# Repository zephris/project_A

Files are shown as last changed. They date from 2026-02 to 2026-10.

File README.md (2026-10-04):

# Project PHBox 
An attempt at an ultra-slim hitbox supporting 13/16 buttom layout, per-key lighting and minimum wired latency, all with uncompromising thinness and weight.

## Specifications
- Dimensions: 296*196*16.5mm (Clap shell customisables)
- Processor: RP2350A
- Connetivity: Wired
- Controller modes: X-input mode, Switch mode, PS3 / D-input mode, Keyboard mode
- Switch: Kailh Choc V1 (hotswappable), with compatability for soldered V2s and 5-pin profiles (Will require custom top-plate with 5-pin full-size switches).
- System compatability: Windows/Unix, Switch/Switch 2, PS3, IpadOS, iOS (USB-C based)
- Feature: 
    - OLED screen
    - Programmable key-mapping with GP-2040-CE firmware
    - Per-key RGB lighting and case-lined diffused lighting
    - Foam-lined, gasket-mounted top-plate to reduce force transfer back onto finger
    - USB-C 3.1 connectivity
    - Stealth flush-sitting passthrough port
    - overclocked for sub-1ms input delay
    - CNC'd alluminium lining plate for thermal dissipation

## TODO:

## Current KiCad project

Latest copper/via cleanup and focused JLCPCB checks: [review and recovery record](stage2_work/fill_via_cleanup_2026-10-03/README.md).

Use the root `Flatbox-rev8.kicad_pro`. The accepted PCB has four copper layers with two dedicated inner GND planes. The 2026-10-03 main-project merge passes ERC, DRC and schematic parity with zero findings and zero open connections. Validation evidence, recovery backup and remaining release checks are in [the merge record](stage2_work/main_merge_2026-10-03/README.md). Eight unnecessary routing bridges were subsequently simplified, removing 16 vias; [the bridge record](stage2_work/bridge_simplification_2026-10-03/README.md) contains the latest verification and PCB backup.

Latest power/USB routing repair and exact validation: [2026-10-04 review](stage2_work/direct_power_usb_2026-10-03/README.md).

## Testing this checkpoint on another computer

Use **KiCad 10**, including its standard symbol/footprint libraries. Open the root `Flatbox-rev8.kicad_pro`; do not open an old autosave, backup or fabrication output. Required project-local libraries and the switch 3D model are included. Some inherited optional third-party 3D model references may be unresolved unless their libraries are installed; this is not proof of mechanical clearance.

Latest accepted changes: [LX cutout, USB ESD/routing and C42](stage2_work/lx_usb_c42_2026-10-04/README.md). This checkpoint contains 146 footprints and 440 numbered pad entries. Recorded exact-main ERC, DRC, unconnected and schematic-parity findings are all zero. Rerun these checks after opening the checkout:

```sh
kicad-cli sch erc --format json -o phbox-erc.json Flatbox-rev8.kicad_sch
kicad-cli pcb drc --refill-zones --schematic-parity --format json -o phbox-drc.json Flatbox-rev8.kicad_pcb
kicad-cli sch export netlist --format kicadxml -o phbox-netlist.xml Flatbox-rev8.kicad_sch
```

On macOS, use `/Applications/KiCad/KiCad.app/Contents/MacOS/kicad-cli` if it is not on PATH. On Windows, use the executable in the KiCad installation's `bin` directory. Review the reports, not just the command exit status. The committed reports record the originating computer and revision; they do not substitute for a fresh run elsewhere.

**Not a manufacturing or firmware release:** historical `order/`, `production/`, BOM and placement exports are stale. No PHBox-validated UF2 or completed SPICE testbench is included. USB2 is intended for a low-power authenticator dongle, not a general-purpose controller power outlet. Firmware mapping, 50% RGB brightness, authentication, suspend current, upstream power budget, USB/ESD, thermal and enclosure tests remain required. Large local candidates/recovery snapshots are deliberately excluded from Git; AGENTS.md retains their provenance for the original workstation.

## Testing methodology and future release steps

This is a validation roadmap, **not a record of completed hardware tests**. The completed checks are schematic/PCB consistency, ERC, DRC, zone refill and pad-net reconciliation. Simulation, firmware behaviour, physical measurements and manufacturing qualification remain future work.

### Configuration baseline

Record the Git commit, KiCad version, board revision, exact firmware SHA-256, exported firmware settings, host OS/console, dongle model, cable and instruments for every test run. Do not infer firmware settings from the schematic.

| Function | Intended configuration |
|---|---|
| MCU/upstream USB | Embedded RP2350A; USB1 is a USB-C **full-speed USB device**, not a USB 3.1 data link |
| OLED | Winstar WEA012864DWPP3N00003, 128×64 I²C; +3V3 supply; GPIO12 SDA / GPIO13 SCL |
| RGB | GPIO8; GRB; D1–D16 at SW1–SW16, then D17–D20 edge LEDs left-to-right; 20 total |
| Brightness | Provisional maximum 127/255 (~50%), including edge effects; verify on the actual firmware |
| 13-button mode | Disable SW6, SW7, SW16 and LED indices 5, 6, 15; same fully populated PCB as 16-button mode |
| USB2 host data | GPIO20 D+ / GPIO21 D− |
| USB2 power control | GPIO7 EN; GPIO17 active-low FAULT input; default off at reset |

USB2 is current-limited by U7/TPS2553 with 200 kΩ ILIM and two 100 µF output capacitors. Its provisional limit is about 115–159 mA, not a promise that any particular dongle works. Explicitly implement and test startup/fault handling; selecting a GP2040-CE enable pin alone does not establish it.

### 1. Software and design regression checks

- Run the KiCad commands above on the exact checkout being tested; retain JSON reports and a fresh XML netlist. Resolve every new finding or document its physical justification; do not weaken rules to obtain a pass.
- Compare symbol pins, PCB pads and actual copper for MCU power/USB, OLED SDA/SCL, LED DIN/DOUT, U6 orientation, U7 switched output and U8 ESD pinout. ERC/DRC alone cannot identify a mutually consistent but incorrect library pin map.
- Confirm zone fills and the local LX exclusion on In1.Cu/In2.Cu/B.Cu. Preserve the neighboring PGND return and connected inner ground planes.
- Keep all test artifacts under a run-specific directory, with pass/fail criteria, model assumptions, raw data and any unresolved limitations. A prior report does not validate a changed board.

### 2. Automated SPICE tests — planned, not implemented

Use separate simulation schematics/netlists so that test sources and behavioural loads cannot accidentally enter the manufacturing schematic. KiCad uses ngspice; batch runs can be driven by a Python/pytest harness and SPICE `.meas` results. Begin with [TI's unencrypted TPS2553 transient model](https://www.ti.com/product/TPS2553#design-development), verify model-pin mapping and ngspice compatibility, and reproduce its reference test before applying it to PHBox.

| Testbench | Sweeps and measurements |
|---|---|
| USB2 startup | Supply ramp, EN timing, 160/200/240 µF output bank, unloaded and representative dongle loads; output rise time, current and FAULT duration |
| USB2 overload/recovery | Loads below/above the limit; output voltage, limiting and recovery after fault removal |
| Shared +5V supply | Cable/source resistance, RGB pulsed-current loads and host hot-plugging; supply minima and settling |
| 3.3V/OLED supply | Startup and load steps using an appropriate regulator model; rail limits and transient response |
| Bypass/data networks | Effective capacitance, ESR, estimated trace/via R/L/C and suitable driver/input models; impedance, ringing and settling |

Use datasheet bounds and measured loads when available; distinguish typical, worst-case and assumed values. Include MLCC bias effects and component tolerances rather than relying on ideal nominal capacitors. A Monte Carlo sample is not a guaranteed worst-case bound. Setting `.temp` does not simulate enclosure heating or self-heating. PCB parasitics are not automatically extracted accurately merely by opening the board in KiCad.

Define assertions from the actual receiving-device voltage/timing limits and the selected models. Do not claim RP2350 firmware execution, regulator-loop stability, USB compliance or ESD survival from generic behavioural models. The present repository has **no complete SPICE test suite**. See [KiCad's simulator documentation](https://docs.kicad.org/10.0/en/eeschema/eeschema.html#simulator).

### 3. Prototype bring-up and power measurements

1. Inspect assembly, polarity and solder joints; check resistance between each rail and GND before power. Support the OLED mechanically; its electrical leads are not mounting posts.
2. Use a current-limited supply through the intended upstream power path, with RGB and USB2 initially off. Never tie a bench supply to a computer's VBUS without a suitable isolated injection arrangement.
3. Verify +5V, +3V3 and the configured MCU core supply; check startup/ripple with short oscilloscope probe returns. Then enable OLED, RGB and USB2 separately and record their incremental loads.
4. Capture upstream current and rail voltages during enumeration, OLED illumination, all-white RGB at 127/255, animation transitions, dongle hot-plugging and repeated boot cycles. A slow USB meter cannot establish peak current or inrush compliance.
5. Use a controlled electronic load for USB2 overload/recovery testing. Capture U7 IN/OUT, EN and FAULT; distinguish legitimate reservoir charging from a sustained fault. Verify the dongle also starts successfully at the low current-limit corner.
6. Test actual USB suspend/resume, not just user inactivity or black LEDs. The existing ~10 mA typical LED-idle estimate is already above the 2.5 mA USB suspend target; power gating or a verified low-power solution may require a hardware revision.

The provisional 500 mA average-current budget is **not closed by measurement**. RGB PWM peaks, upstream USB power declaration/configuration, cable drop, startup and fuse derating remain checks. Stop on abnormal current, temperature or rail collapse; do not use an uncontrolled wire short as a fault test.

### 4. Firmware and interoperability tests

- Verify each action/option button, simultaneous presses, SOCD behaviour and both 13/16-button modes. Confirm disabled buttons/LEDs stay disabled after reboot.
- Exercise each LED individually and solid red/green/blue to verify index/colour order; verify OLED refresh and button activity together.
- Test enumeration, repeated reconnects and suspend/resume on the intended operating systems, both USB-C cable orientations and representative compliant cables.
- Use a Python/pytest harness with HIDAPI in a supported HID mode for automated report checks. End-to-end input testing needs real button stimulation; software-generated input on the PC does not test the PCB contacts. Do not assume HID tooling tests XInput modes identically.
- Use Wireshark/USBPcap on Windows or usbmon on Linux for PC-side protocol diagnostics. The PC cannot directly capture the USB2 dongle bus behind the MCU; use firmware logs or an inline USB protocol analyzer for that side.
- Test the actual authenticator and target console over extended sessions, including unplug/replug and recovery. Successful PC enumeration is not proof of console authentication or official platform approval.
- Measure physical-input-to-host-report latency with an external stimulus/time reference; USB polling interval alone does not establish end-to-end latency.

Tools: [HIDAPI](https://github.com/libusb/hidapi), [pytest](https://docs.pytest.org/en/stable/), [Wireshark USB capture](https://wiki.wireshark.org/CaptureSetup/USB), [USB-IF protocol/electrical tools](https://www.usb.org/compliancetools). USB3CV can test USB 2.0 devices, but use a dedicated test computer/controller because it takes over the host controller.

### 5. Physical qualification

- Check regulator startup/ripple and core-rail load transients. The LX keepout is a layout improvement, not proof of regulator stability or reduced emissions.
- Test the assembled enclosure at room temperature and the specified **60 °C maximum ambient** until temperatures stabilize. Record fuse, regulator, U7 and MCU temperatures/rail behaviour. Surface temperature is not junction temperature; do not credit the aluminium plate as cooling without verified thermal coupling.
- Obtain factory stackup/impedance data or a coupon; obtain appropriate full-speed USB waveform/eye measurements using a suitable scope, probe and fixture. Packet captures and matched via counts do not establish 90 Ω or electrical compliance.
- Use a competent lab for controlled ESD and applicable emissions/immunity testing of the assembled enclosure and connectors. Do not substitute improvised static shocks for the specified test method.
- Verify actual switch housing/keycap light paths, solder access, OLED standoffs/window, USB insertion clearance, insulating layers, screw/hole clearances and the total enclosure stack. Component bodies/courtyards retain 2.5 mm PCB-edge clearance except USB1 and the four edge LEDs; unresolved mounting-hole exceptions must be explicitly approved.

### 6. Manufacturing and release gate

1. Freeze one reviewed source revision. Manufacture one fully populated 16-button board; 13-button operation is a firmware/mechanical-cover mode, not a reduced BOM.
2. Recheck exact MPN, package, footprint/pinout, polarity, lifecycle and current supplier availability. For JLCPCB, verify each LCSC identity and Basic/Extended status at ordering time. Confirm the SK6805-EC15 purchased variant against the `-001` datasheet; generic substitutes are not automatically acceptable.
3. Agree the four-layer stackup, copper weights, impedance geometry, drill/via limits, soldermask, stencil/reflow process, double-sided assembly and mechanical tolerances with the manufacturer. Review exposed-pad soldering, via treatment, 0402 access, USB2 on B.Cu and opposite-side U8/C44 placement.
4. Regenerate BOM, top/bottom placement files, all four copper-layer Gerbers, masks, silkscreens, Edge.Cuts and plated/non-plated drills **from that same revision**. Inspect them in an independent viewer; verify orientation, mirror conventions, drill alignment and placement datum. Never reuse the historical `order/` or `production/` exports.
5. Review the assembler's BOM/CPL matching and visual assembly preview. Check every polarized IC/diode/capacitor, connector and LED rotation; retain explicit DNP/exclusion and hand-assembly notes. Include OLED mounting hardware and other non-schematic mechanical items separately.
6. Build a small first-article batch and execute the above tests before a larger production run. Clearly distinguish a risk-accepted engineering prototype order from a qualified production release.
7. Archive source commit, tool versions, reports/raw captures, approved parts/alternatives, exact fabrication files, assembly preview, mechanical drawings, firmware image/hash and exported settings for both modes. Attach a release manifest/checksums so the build can be reproduced.

Manufacturing exit requires reviewed electrical/physical checks, proven power/suspend/thermal behaviour, verified mechanical fit, compatible firmware/dongle operation and coherent assembly outputs. Clean ERC/DRC alone is not manufacturing sign-off.

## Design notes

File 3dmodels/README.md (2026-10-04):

# Kailh Choc hot-swap socket model

Source: https://github.com/perigoso/keyswitch-kicad-library
Pinned revision: `9edbd5ea3f5f4e36cbdfaefdf3d8b5c28277a416`

`SW_Hotswap_Kailh_Choc_V1.step` is the upstream `.stp` file renamed without modifying its contents. Its WRL counterpart is also included. Upstream declares the library dual licensed under MIT and CC-BY-SA 4.0; copies are included alongside these assets. Credit: Rafael Silva (perigoso) and contributors to keyswitch-kicad-library.

This is the socket body model, not the installed switch or keycap. Its matching upstream `SW_Hotswap_Kailh_Choc_V1V2` footprint has exactly the same pads and NPTH geometry as the existing PHBox optical variant. The replacement project-local footprint retains PHBox optical silkscreen adaptations and references `${KIPRJMOD}/3dmodels/SW_Hotswap_Kailh_Choc_V1.step`, with upstream zero offset/rotation and unit scale. All SW1–SW16 PCB instances and schematic footprint properties use `PHBox_Repair:SW_Hotswap_Kailh_Choc_V1V2_3D_Optical`.

Model visualization does not establish switch-housing, keycap or enclosure fit; those release checks remain.

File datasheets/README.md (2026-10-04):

# PHBox RGB LED datasheet cache

Downloaded 2026-09-25 for comparison of the candidate LED and the part named by the former PCB footprint. The OPSCO PDF is the design reference for schematic LEDs D1–D20 and the project PCB footprint; confirm that the purchased `SK6805-EC15` is the `-001` variant documented here.

| Cached PDF | Document identity | Source | SHA-256 |
|---|---|---|---|
| `OPSCO_SK6805-EC15-001_C2890035.pdf` | OPSCO SK6805-EC15-001, Rev A/1, dated 2025-08-07; linked by LCSC C2890035, which lists MPN SK6805-EC15 | https://datasheet.lcsc.com/datasheet/pdf/0f4b58ac8908ccf8037b2d7ca0ec1e91.pdf?productCode=C2890035 | `7862e1b38734e98826262766ff7b654292008c626bc265c91798eabcd447df0f` |
| `Newstar_EC15_SK6812.pdf` | Newstar EC15, Rev 02, dated 2018-09-18; manufacturer-authored document mirrored by Datasheet4U | https://datasheet4u.com/pdf/1313775/EC15.pdf | `66dc63d9f50667548e5edd46bea4ba234cb3b60c5637b8106ce58da3026aa4cf` |

The KiCad `LED_SK6812_EC15_1.5x1.5mm` footprint points to `http://www.newstar-ledstrip.com/product/20181119172602110.pdf`, which returned HTTP 404 on 2026-09-25. The cached Newstar PDF is a mirror of a manufacturer-authored EC15 sheet; its document identifies the model as `EC 15`, not a uniquely orderable `SK6812-EC15` manufacturer part number.

For the two design review items: the OPSCO candidate and Newstar EC15 agree on pins 1 DIN, 2 VDD, 3 DOUT, 4 GND and 1.5×1.5×0.65 mm body size. OPSCO's recommended land drawing shows 0.55×0.55 mm pads with 0.40 mm gaps; Newstar's shows 0.60×0.50 mm pads with 0.40 mm gaps. The former embedded PCB footprint had 0.50×0.50 mm pads on 0.90 mm horizontal and vertical pitch. The PCB's 20 LED footprints now use the OPSCO land drawing and orientation, but the exact supplied variant and assembly-process suitability still need confirmation.

| Electrical item | OPSCO SK6805-EC15-001 | Newstar EC15 Rev 02 |
|---|---|---|
| Supply range in sheet | 3.7–5.5 V | 3.5–5.5 V, in an “absolute maximum ratings” table; do not treat this as a recommended range |
| DIN high threshold at 5 V | ≥0.78×VDD = 3.9 V | ≥0.7×VDD = 3.5 V |
| Color byte order | GRB | GRB |
| Reset low interval | ≥200 µs | >80 µs |
| Idle current | 0.5 mA typical | 1 mA typical |
| RGB channel current | 5 mA typical, 6.3 mA listed maximum per channel | Not specified in this sheet; `0.1 Watt` appears in its cover description but does not establish a current limit |

Use the OPSCO sheet, not the Newstar figures, to design around C2890035. In particular, a 3.3 V MCU output falls below both stated 5 V DIN thresholds, and the two parts have different reset requirements. The comparison does not establish interchangeable parts or a production-approved footprint.

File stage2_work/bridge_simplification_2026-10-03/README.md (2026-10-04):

# Bridge simplification — 2026-10-03

Reviewed 30 isolated outer-layer via-to-via track chains, including longer detours. Tested same-geometry layer consolidation on a separate candidate with matching project/rules and native zone refill/DRC. Conflicting neighboring chains were resolved before the final trial. USB data routing retained.

Merged eight successful sections into the root PCB, removing 16 signal vias. All track widths, net assignments, endpoint coordinates, and 144 footprint/pad geometries are preserved; only 16 existing track segments changed B.Cu to F.Cu. Both inner GND planes remain one filled outline each; their filled area increased from 44839.4045 to 44846.6328 mm² because removed signal vias no longer require clearance holes.

Recovery: `before.kicad_pcb` is the exact main-board backup immediately before the merge. `inventory.json`, `accepted.json`, `reasons.json`, trial reports, and `audit.json` record inspection and validation. Retained entries failed clearance or connectivity in the attempted consolidation, or conflicted with the better accepted consolidation of neighboring sections; this does not rule out future rerouting with different geometry.

| Net | Layer-hop length (mm) | Result |
|---|---:|---|
| UP2 | 7.337 | Retained: clearance, track_dangling, tracks_crossing, unconnected_items |
| Net-(D17-DIN) | 6.743 | Retained: track_dangling, unconnected_items |
| Net-(D13-DIN) | 1.482 | Retained: track_dangling, unconnected_items |
| UP3 | 7.354 | Retained: clearance, track_dangling, tracks_crossing, unconnected_items |
| SDA | 10.499 | Retained: track_dangling, tracks_crossing, unconnected_items |
| UP2 | 9.276 | Retained: clearance, track_dangling, tracks_crossing, unconnected_items |
| Net-(U4-D+_to_connector) | 3.505 | Retained: clearance, solder_mask_bridge |
| Net-(D17-DIN) | 88.866 | Retained: clearance, shorting_items, tracks_crossing |
| Net-(D17-DIN) | 1.236 | Simplified to F.Cu |
| Net-(D16-DIN) | 113.988 | Retained: clearance, tracks_crossing |
| Net-(D12-DOUT) | 8.582 | Simplified to F.Cu |
| Net-(D13-DIN) | 0.920 | Simplified to F.Cu |
| Net-(D13-DIN) | 1.460 | Simplified to F.Cu |
| SCL | 19.042 | Retained: tracks_crossing |
| UP3 | 9.398 | Retained: shorting_items, track_dangling, tracks_crossing, unconnected_items |
| RGB | 28.285 | Retained: tracks_crossing |
| /LED_BUFFER_Y | 5.402 | Retained: shorting_items, solder_mask_bridge, tracks_crossing |
| SDA | 1.388 | Retained: clearance, tracks_crossing |
| SDA | 18.956 | Retained: clearance, shorting_items, track_dangling, tracks_crossing, unconnected_items |
| Net-(D9-DIN) | 1.226 | Simplified to F.Cu |
| Net-(D9-DOUT) | 0.921 | Simplified to F.Cu |
| OPT2 | 5.837 | Retained: tracks_crossing |
| Net-(D1-DOUT) | 6.236 | Retained: clearance |
| OPT6 | 5.862 | Retained: tracks_crossing |
| OPT5 | 5.862 | Retained: tracks_crossing |
| OPT4 | 5.862 | Retained: tracks_crossing |
| OPT3 | 5.862 | Retained: tracks_crossing |
| /LED_DATA_IN | 6.991 | Retained: tracks_crossing |
| Net-(D5-DIN) | 10.442 | Simplified to F.Cu |
| Net-(D6-DIN) | 1.736 | Simplified to F.Cu |

Final main-project verification: native zone refill/DRC found 0 violations, 0 open items and 0 schematic parity findings. Fresh ERC found 0 violations. Fresh XML netlist matches all 432 fitted PCB pad entries. Main/candidate S-expressions are identical excluding regenerated filled polygons; both main inner GND planes remain one outline with the same area as the candidate. `main-verification.json` records the final main PCB hash. No manufacturing/firmware output was regenerated.

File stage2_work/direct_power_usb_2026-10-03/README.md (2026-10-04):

# Direct power traces and moved USB-C repairs — 2026-10-04

## Accepted main revision

The power and USB-C workers edited separate candidates, then a third worker reviewed current/voltage-drop margins, actual copper connectivity and ground contours. Root reviewed the object deltas, combined the repairs, ran native checks, and promoted only the accepted PCB to `Flatbox-rev8.kicad_pcb`. Existing dirty files are preserved. The user confirmed PCB editor saved and closed; native Codex subagents explicitly authorized for this task.

- Broad F.Cu +5V and B.Cu +3V3 backgrounds replaced by GND. Local regulator/core and useful local power copper remain.
- Fifteen 0.30mm LED bypass branches added, including C20 and C35. C26 already had copper. Three 0.60mm +5V joins, two 0.50mm +3V3 joins, and a short MCU 0.15mm escape followed by 0.25mm connection added. One orphan +3V3 zone and 17 old track/via objects removed; no new vias.
- USB1 remains at the user's moved location (158.432180,38.843118), rotation180. Its VBUS, CC, reversible data and GND/shield fanouts reconnected by changing 25 existing tracks. VBUS stem/D21 cathode0.60mm; D21 ground0.50mm. No footprint placement or pad changes.
- 144 footprints unchanged; 432 checked pads match fresh XML; 1,826 track/via objects. All surviving unrelated copper matches baseline, with precisely the two workers' accepted changes.
- Both inner GND planes remain one continuous outline,44790.72595mm² each; no inner signal tracks. Outer GND has29 front/21back contours. Every contour has an actual plated GND anchor to both inner planes, checked by filled-polygon intersections. No floating contour was accepted. Always-remove-islands enabled.

## Final validation and evidence

Exact main native KiCad10.0.6: **ERC0; DRC0 errors/0warnings; opens0; schematic parity0**. Zone refill/save completed. `git diff --check` passes. No DRC rules/severities changed for these repairs.

- `main-drc.json`, `main-erc.json`, `merged-netlist.xml`, `main-audit.json`: final checks.
- `merge-deltas.json`, `power/power-audit.json`, `usb/usb-audit.json`: complete UUID/geometry deltas.
- `usb/merged-manual-trace.json`: actual USB1 pad-to-protection/CC trace paths and GND plane intersections.
- `current_review/native-power-connectivity.json`: actual copper continuity for LED/bypass, MCU/flash/OLED, and isolated host output.
- `current_review/ground-anchors.json`: actual anchors for all50 outer GND contours.
- `current_review/current-sizing.md`: current sizing assumptions, calculations and primary sources.
- `pre-merge-main/`: exact main source backup. `baseline/`: starting candidate with moved USB1 and stale routing. Workers/merged are isolated review files, not the main project to edit next.

Current screen assumes35µm outer copper: provisional average stress~473mA; simultaneous planning peak~662mA. New traces pass conservative thermal/drop screening, but this does not close upstream USB500mA compliance. Firmware power sequencing/brightness, actual current waveforms, fuse temperature and regulator/OLED/dongle loading need hardware tests. Inherited USB pair asymmetry/impedance remains deferred; connector mating/enclosure fit, factory stackup and assembly checks remain. No manufacturing outputs, firmware, commit or push made in this task.

A one-run1:15AM Perth resume automation was created as a usage-limit fallback. It checks whether this work is already complete and takes no further action if so.

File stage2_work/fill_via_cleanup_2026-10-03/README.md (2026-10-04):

# Fill/via cleanup and focused JLCPCB review — 2026-10-03

## Applied to the main PCB

- Removed 58 remote, untracked GND stitching vias. Retained every via with a nearby ground track, any pad within 3 mm, any non-GND layer-transition via within 3 mm, the perimeter fence, and the MCU/USB power-control clusters. The removed vias include all five illustrated in the user's screenshot. These distance criteria are a conservative layout screening rule, not a measured EMC result.
- Removed one empty +1V1 zone and one obsolete +1V1 zone superseded by the unified core-power pour.
- Consolidated 13 F.Cu +5V and B.Cu +3V3 zone definitions into their existing same-net background pours. Native refill/DRC proves the consolidated candidate remains connected. Front background fill went from 171 contour objects to 2; those earlier contours were not 171 electrically floating islands.
- Raised zones with 0.0254 mm minimum thickness to 0.10 mm (B.Cu zones already use 0.20 mm). This eliminates the two sliver warnings in the stricter clearance trial.
- Moved C40's GND via from (156.45,77.300618) to (156.45,76.55) mm, outside its solder pad, retaining the via UUID and adding two short 0.15 mm F.Cu GND fanout segments. No via centers now lie within SMD solder pads in the native geometry check.
- Strengthened the project hole-to-copper clearance from 0.15 to 0.20 mm and solder-mask-opening-to-other-net-copper clearance from 0 to 0.09 mm. Other project settings remain unchanged.

All 144 footprints/pad geometries/UUIDs/placements are unchanged. Signal routes and power tracks are unchanged. Only one remaining GND via moved; two GND fanout segments were added. There are 319 vias, including 205 GND vias, and 1771 total track/via objects. Both inner GND fills remain single continuous outlines; area is 44788.0646 mm² each after the increased clearance/refill.

## Why power pours remain

The temporary no-background trial broke two LED bypass +5V connections (C20/C35) and three MCU +3V3 network links, plus produced dangling power items. That trial was rejected. The broad pours have functional power connections and are not removable filler. A future conversion of unused area to GND must preserve or reroute those supply links and verify return geometry; do not change the power-pour net label in place.

## Solder mask and exposed +5V

The board contains no non-pad mask graphics or mask zones opening large copper areas. Front/back global via tenting is enabled. The red copper display is not a representation of bare finished copper. Broad +5V copper is covered by solder mask; normal component solder lands remain exposed. Solder mask does not replace mechanical insulation/clearance from the metal enclosure.

For new routing, use localized power distribution and grounded unused-area copper where practical, with suitable stitching; retain the two dedicated inner GND planes. Large power pours are not inherently a manufacturing fault. This is a layout preference and must be evaluated against actual PDN/return paths.

## Focused JLCPCB checks

Profile: four-layer FR-4, 1 oz outer copper, routed board edge, standard tented vias, and a mask color supporting 0.10 mm webs (green/red/yellow/blue/purple). Black/white requires 0.13 mm webs per the current capability table; this report does not approve that different option.

| Item | Board / rule | JLCPCB guide |
|---|---|---|
| Minimum track width | 0.15 mm measured | 0.09 mm multilayer, 1 oz |
| Minimum copper clearance | 0.10 mm rule; zones 0.15/0.1524 mm | 0.09 mm multilayer trace spacing; separate pad rules apply |
| Vias | ≥0.45045 mm diameter, 0.30–0.35 mm drill | Diameter should exceed drill by 0.10 mm, preferably 0.15 mm; preferred minimum drill 0.20 mm |
| Via annulus | ≥0.075075 mm measured | Meets preferred 0.15 mm diameter increase; do not confuse via rule with component PTH annular-ring rules |
| Via tenting | Both sides enabled | Ideally ≤0.40 mm holes; not guaranteed for large holes >0.50 mm |
| Copper to routed edge | ≥0.30 mm enforced and native DRC passes | ≥0.20 mm; V-cut has a different ≥0.40 mm rule |
| Hole-to-copper | ≥0.20 mm strengthened rule | Inner via-hole-to-copper and via-hole-to-track minimum 0.20 mm; component PTH rules are distinct |
| Mask openings to neighbor traces | ≥0.09 mm strengthened rule | ≥0.09 mm |
| Mask web | 0.10 mm | 0.10 mm with listed mask colors; black/white 0.13 mm |
| Via-in-SMD-pad centers | None after C40 repair | Filled/capped process is required for conventional via-in-pad assembly; simple tenting is not plated-over via filling |
| Copper balance | Broad solid outer power fills retained; both inner GND planes continuous | JLCPCB recommends copper in unused areas and avoiding highly unbalanced coverage |

## Sources

- [JLCPCB current capabilities](https://jlcpcb.com/capabilities/pcb-capabilities)
- [JLCPCB via-covering guidance](https://jlcpcb.com/help/article/pcb-via-covering)
- [JLCPCB copper pour basics](https://jlcpcb.com/blog/pcb-copper-pour-basics)
- [JLCPCB solder mask guide](https://jlcpcb.com/blog/basic-design-of-solder-mask)
- [KiCad 10 solder mask and zone documentation](https://docs.kicad.org/10.0/en/pcbnew/pcbnew.html)

This is a focused copper/via/mask review, not a whole-board fabrication or EMC sign-off. Exact stackup/impedance, final Gerber/assembly preview and mechanical/hardware release gates remain. Manufacturing and firmware outputs were not regenerated.

## Evidence and recovery

`before/` contains the exact pre-cleanup PCB/project/schematic/rules. `inventory.json`, `trial-removals.json`, `consolidation-removals.json`, `audit.json` and `dfm-measurements.json` record changes. Rejected background-removal and stricter-rule trials are preserved separately. `consolidation-drc.json` and `main-drc.json` report zero violations, unconnected items and schematic parity errors on their exact revisions. Fresh main ERC/netlist checks are recorded alongside them.

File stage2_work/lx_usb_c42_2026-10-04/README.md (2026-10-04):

# Accepted local LX, USB and C42 changes — 2026-10-04

Merged into root Flatbox-rev8.kicad_pcb and .kicad_sch after the user confirmed both editors saved/closed. Root remains the accepted source; early trial boards/reports in this directory are rejected checkpoints, not release files. `pre-edit/` is the recovery checkpoint.

## Accepted changes

- Added named RP2350_LX_copper_cutout rule areas on In1.Cu, In2.Cu and B.Cu. Their small stepped outline covers the LX-side inductor pad and LX corridor, not the neighboring PGND return or the entire regulator. It excludes tracks, vias and zone fills without removing the existing top-layer LX copper/power loop. Native filled-copper queries at L1's LX pad (147.03218,50.816558) changed from GND present to absent on both inner layers. Each inner plane remains one connected filled contour.
- Moved existing C42 on B.Cu from (210,70.5) to (216.6,69.4), rotation 180°. Its +5V pad is now 1.688 mm from U7 IN rather than 6.98 mm. Removed its two old back-side fanouts and the dedicated front-side supply stub/via; added a short IN branch and local ground via. U7 and surrounding power/control routing were not moved or rerouted.
- USB1 keeps its connector, filter, TVS, CC components and protected MCU pair in place. Replaced two local connector-side D− front tracks with a back-side section and two 0.45 mm/0.30 mm vias, eliminating the prior two-via-versus-zero-via imbalance. The original D+ path and reversible connector fanout are unchanged. Existing nearby ground transitions remain. This is a limited full-speed layout improvement, **not** validation of 90 Ω impedance or a claim of ideal pair coupling everywhere.
- Added U8, ST USBLC6-2SC6 (JLCPCB C7519), on B.Cu at (221.1,62.4), with standard Package_TO_SOT_SMD:SOT-23-6 footprint. Pins 1/6 are HD+, 3/4 HD−, 2 GND, 5 USB_HOST_5V. Both channels have actual continuous flow-through PCB copper connecting their two pads; continuity does not depend on the analyzer understanding internal IC connections. Only the connector-side host fanout was replaced; the long host pair and R5/R7 remain unchanged.
- Added C44, 100 nF/16 V X7R Samsung CL05B104KO5NNNC (C1525), on F.Cu opposite U8 at (221.4,61.4), rotation 180°. Short dedicated ground and switched-VBUS vias connect it to U8. Its supply comes from the existing switched output bank, never upstream +5V. This small bypass does not change U7's ILIM, GPIO controls or bulk-capacitor architecture.

## Verification and object scope

Fresh exact-main `main-erc.json` and `main-drc.json`: ERC 0, DRC 0, unconnected 0, schematic parity 0. No rule was disabled or weakened. 146 footprints / 440 numbered PCB pad entries are synchronized. Independent XML-to-pad checks and UUID/physical geometry comparisons are in audit.json. Only existing footprint C42 moved; U8/C44 are the two additions. 18 old copper objects removed, 34 added, **every surviving track/via unchanged**; total 1790→1806. The USB group merely dropped deleted member UUIDs.

Zone refill is included in the accepted board. Both inner planes remain single connected contours; all 29 front and 22 back ground contours have actual plated anchors into both inner planes (`ground-anchors.json`). This does not establish measured EMI/ESD performance. Local bottom-layer layout was visually reviewed in the exported preview; fab-layer annotation overlap is not silkscreen overlap.

Candidates were generated with KiCad 10 pcbnew, then loaded/refilled/checked by KiCad CLI. A quote-aware balanced-form merge applied only changed objects and filled zones, preserving unrelated main forms/UUIDs. Project .pro/.dru and existing libraries were unchanged. Helpers here regenerate **candidates only**; merge_patch.py rejects a main source that differs from its pre-edit checkpoint and must not be rerun blindly after this merge.

## Sources and remaining gates

ST [USBLC6-2 datasheet](https://www.st.com/resource/en/datasheet/usblc6-2.pdf), DS4260 Rev 7, confirms the SC6 pinout, SOT-23-6 package, low line capacitance and 100 nF VBUS bypass guidance. [JLCPCB C7519](https://jlcpcb.com/partdetail/STMicroelectronics-USBLC62SC6/C7519) supplied the sourcing identity; availability still needs rechecking before purchase. The PDF was inspected online, but direct download failed twice (HTTP/2 reset and HTTP/1.1 timeout); do not claim a local cached PDF exists.

Regulator cutout follows [RP2350 datasheet §6.3.8](https://datasheets.raspberrypi.com/rp2350/rp2350-datasheet.pdf), while retaining the neighboring ground returns. U7 input bypass placement follows the [TPS2553 layout guidance](https://www.ti.com/lit/ds/symlink/tps2553.pdf).

Corrected two transcription errors in the earlier final-review table: RP2350A native USB D+ is pin 52 and D− pin 51; TPS2553 pin 4 is FAULT and pin 5 ILIM. The actual schematic/PCB mappings were already correct and were not changed.

Still required: factory stackup/impedance model or coupon, USB functional/eye/ESD tests, regulator startup/ripple checks, U7 inrush/FAULT behavior, real upstream/suspend-current and thermal measurements, enclosure/assembly clearance (including opposite-side C44/U8), and manufacturing/BOM/firmware release checks. No firmware image, manufacturing outputs, commit or push was produced.

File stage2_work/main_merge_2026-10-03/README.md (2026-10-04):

# PHBox main-project merge — 2026-10-03

The repaired four-layer candidate was promoted into the root `Flatbox-rev8.kicad_pcb` and its matching schematic. Open the root `Flatbox-rev8.kicad_pro` for subsequent work.

## Validation of the merged main files

High confidence, local KiCad 10.0.6 file/connectivity evidence:

- ERC: **0 findings** (`main-erc.json`). Main-project ERC settings were retained.
- DRC: **0 errors / 0 warnings / 0 open connections / 0 schematic parity findings** (`main-drc.json`, after final refill/save).
- All **144 footprints** and **1,843 track/via objects** match the accepted four-layer candidate. All **432 PCB pad entries** match the fresh schematic netlist; footprint schematic UUID paths match (`merge-audit.json`, `main-netlist.xml`).
- Both inner GND layers have one continuous filled outline (~44,839 mm² each), with no inner signal tracks.
- The 76 checked fixed component positions, rotations and sides match the former main board, including action/option switches, MCU, OLED, USB ports, LEDs and MCU support parts.
- Component references, values and sourcing properties match the former main schematic. Its only component-pin net changes are the accepted no-connect declarations on unused U1 SWCLK/SWD pins 24/25. The former main schematic was byte-identical to the candidate's pre-ERC-repair schematic baseline.
- `git diff --check` passes.

## Merged files and settings

The root PCB, schematic and `.kicad_dru` now contain the repaired design. The project imports the candidate's DRC rules/severities and routing net classes. Existing main schematic/ERC, plotting and editor settings remain. `PHBox.kicad_sym` gained only the three matching frozen legacy symbol definitions; existing definitions remain intact. `PHBox_Repair.pretty` and its registration were added; existing library registrations remain. Blank-line whitespace in the schematic was cleaned without changing its circuit.

The .dru permits only the 16 intentional matching action-switch/LED courtyard overlaps. Other reported rules remain enabled. Existing ignored checks are listed in the DRC report, including missing courtyards; their mechanical verification still requires actual part geometry.

## Recovery

`before/` contains the exact previous main PCB/schematic/project/library tables/symbol library/AGENTS.md. `manifest.json` records before/candidate/final hashes and the absent files before promotion. Restore source files from `before/` into the root project if recovery is needed; retaining the new library registration and rule file would not reproduce the former state, so follow the manifest for those additions. Preserve subsequent edits when restoring.

The candidate and separate `stage2_work/Flatbox-rev8.kicad_pcb` were retained. Existing editor-state/autosave files and manufacturing/firmware outputs were preserved.

## Remaining release checks

Confirm the actual JLCPCB stackup/impedance and DFM, mechanical/enclosure/switch/OLED clearances, USB and bypass return geometry, power/current/thermal/startup behavior, RGB waveforms, GP2040-CE configuration and hardware operation. Quilter USB differential-pair PRC remains deferred as previously directed. Complete BOM/CPL/assembly-preview review and manufacturing outputs from the accepted main revision. This merge validation covers KiCad connectivity, library consistency, placements and fills; no new thermal/EMC/SPICE or manufacturing-release review was performed.

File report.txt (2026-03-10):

Info: Output directory 'C:\Users\admin\Documents\KiCad\9.0\projects\project_a_latest\project_A\order' created.
Plotted to 'C:\Users\admin\Documents\KiCad\9.0\projects\project_a_latest\project_A\order\Flatbox-rev8-F_Cu.gtl'.
Plotted to 'C:\Users\admin\Documents\KiCad\9.0\projects\project_a_latest\project_A\order\Flatbox-rev8-B_Cu.gbl'.
Plotted to 'C:\Users\admin\Documents\KiCad\9.0\projects\project_a_latest\project_A\order\Flatbox-rev8-F_Silkscreen.gto'.
Plotted to 'C:\Users\admin\Documents\KiCad\9.0\projects\project_a_latest\project_A\order\Flatbox-rev8-B_Silkscreen.gbo'.
Plotted to 'C:\Users\admin\Documents\KiCad\9.0\projects\project_a_latest\project_A\order\Flatbox-rev8-F_Mask.gts'.
Plotted to 'C:\Users\admin\Documents\KiCad\9.0\projects\project_a_latest\project_A\order\Flatbox-rev8-B_Mask.gbs'.
Plotted to 'C:\Users\admin\Documents\KiCad\9.0\projects\project_a_latest\project_A\order\Flatbox-rev8-Edge_Cuts.gm1'.
Info: Done.
Info: Done.

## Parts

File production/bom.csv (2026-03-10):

Designator | Footprint | Quantity | Value | LCSC Part #
C1, C10, C18, C3, C4, C5, C6, C7, C8, C9 | 0402 | 10 | 100n | C1525
C11, C12, C13, C2 | 0402 | 4 | 4.7u | C23733
C14, C15 | 0402 | 2 | 1u | C52923
C16, C17 | 0402 | 2 | 15p | C1548
C19 | CP_EIA-3528-21_Kemet-B | 1 | 100u | C16133
F1 | 0805 | 1 | 500m | C2833485
L1 | L_pol_2016 | 1 | 3.3u | C42411119
R1 | 0402 | 1 | 33 | C25105
R10, R11 | 0402 | 2 | 5.1k | C25905
R2, R3 | 0402 | 2 | 27 | C138021
R4, R6, R8 | 0402 | 3 | 1k | C11702
R5, R7 | 0402 | 2 | 22 | C102906
SW1_2, SW3_2 | SW_Hotswap_Kailh_Choc_V1V2 | 2 | GPIO10
SW10 | SW_Hotswap_Kailh_Choc_V1V2 | 1 | GPIO26
SW11 | SW_Hotswap_Kailh_Choc_V1V2 | 1 | GPIO28
SW12 | SW_Hotswap_Kailh_Choc_V1V2 | 1 | GPIO18
SW13 | SW_Hotswap_Kailh_Choc_V1V2 | 1 | GPIO25
SW14 | SW_Hotswap_Kailh_Choc_V1V2 | 1 | GPIO27
SW15 | SW_Hotswap_Kailh_Choc_V1V2 | 1 | GPIO29
SW16, SW7, SW9 | SW_Hotswap_Kailh_Choc_V1V2 | 3 | GPIO24
SW19, SW20 | SW_SPST_EVQP2_ShortPushTravel_H2.1mm | 2 | SW_Push | C318884
SW2_2 | SW_Hotswap_Kailh_Choc_V1V2 | 1 | GPIO9
SW4_2 | SW_Hotswap_Kailh_Choc_V1V2 | 1 | GPIO11
SW5_2, SW6_2 | SW_Hotswap_Kailh_Choc_V1V2 | 2 | GPIO16
SW8 | SW_Hotswap_Kailh_Choc_V1V2 | 1 | GPIO19
U1 | RP2350-QFN-60-1EP_7x7_P0.4mm_EP3.4x3.4mm_ThermalVias | 1 | RP2350_60QFN | C42411118
U2 | SOT-23-5 | 1 | TLV73333PDBV | C134139
U3 | SOIC-8_5.23x5.23mm_P1.27mm | 1 | W25Q128JVS | C97521
U4 | ECMF02-4CMX8 | 1 | ~ | C717678
U? | OLED-TH_L38.0-W12.0_HS91L02W2C01 | 1 | OLED-TH_L38.0-W12.0_HS91L02W2C01
USB1 | HRO-TYPE-C-31-M-12-Assembly | 1 | HRO-TYPE-C-31-M-12 | C165948
USB2 | USB_A_TE_292303-7_Horizontal | 1 | USB_A | C2763302
Y1 | Crystal_SMD_3225-4Pin_3.2x2.5mm | 1 | ABM8-272-T3 | C20625731

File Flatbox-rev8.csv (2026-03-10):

Id | Designator | Footprint | Quantity | Designation | Supplier and ref
1 | SW3,SW1 | SW_Hotswap_Kailh_Choc_V1V2 | 2 | GPIO10
2 | SW4 | SW_Hotswap_Kailh_Choc_V1V2 | 1 | GPIO11
3 | SW5,SW6 | SW_Hotswap_Kailh_Choc_V1V2 | 2 | GPIO16
4 | SW12 | SW_Hotswap_Kailh_Choc_V1V2 | 1 | GPIO18
5 | SW13 | SW_Hotswap_Kailh_Choc_V1V2 | 1 | GPIO25
6 | SW14 | SW_Hotswap_Kailh_Choc_V1V2 | 1 | GPIO27
7 | SW15 | SW_Hotswap_Kailh_Choc_V1V2 | 1 | GPIO29
8 | SW8 | SW_Hotswap_Kailh_Choc_V1V2 | 1 | GPIO19
9 | SW9,SW16,SW7 | SW_Hotswap_Kailh_Choc_V1V2 | 3 | GPIO24
10 | SW10 | SW_Hotswap_Kailh_Choc_V1V2 | 1 | GPIO26
11 | SW11 | SW_Hotswap_Kailh_Choc_V1V2 | 1 | GPIO28
12 | SW2 | SW_Hotswap_Kailh_Choc_V1V2 | 1 | GPIO9
13 | R11,R10 | R_0402_1005Metric | 2 | 5.1k
14 | USB1 | HRO-TYPE-C-31-M-12-Assembly | 1 | HRO-TYPE-C-31-M-12
15 | REF**,REF**,REF**,REF**,REF**,REF**,REF**,REF**,REF**,REF**,REF**,REF**,REF**,REF**,REF**,REF**,REF** | C_0402 | 17 | C_0402_1005Metric
16 | R7,R5 | R_0402_1005Metric | 2 | 22
17 | C6,C9,C1,C8,C10,C18,C7,C5,C4,C3 | C_0402_1005Metric | 10 | 100n
18 | REF**,REF**,REF**,REF**,REF**,REF**,REF**,REF**,REF**,REF**,REF**,REF**,REF**,REF**,REF**,REF**,REF**,REF**,REF**,REF** | LED_SK6812_EC15_1.5x1.5mm | 20 | LED_SK6812_EC15_1.5x1.5mm
19 | U4 | ECMF02-4CMX8 | 1 | ~
20 | C12,C13 | C_0402_1005Metric_small_pads | 2 | 4.7u
21 | C17,C16 | C_0402_1005Metric | 2 | 15p
22 | C14,C15 | C_0402_1005Metric | 2 | 1u
23 | REF**,REF** | C_0603 | 2 | C_0603_1608Metric
24 | R3,R2 | R_0402_1005Metric | 2 | 27
25 | REF** | SOT-23-5 | 1 | SOT-23-5
26 | F1 | Fuse_0805_2012Metric | 1 | 500m
27 | SW19,SW20 | SW_SPST_EVQP2_ShortPushTravel_H2.1mm | 2 | SW_Push
28 | C11,C2 | C_0402_1005Metric | 2 | 4.7u
29 | U? | OLED-TH_L38.0-W12.0_HS91L02W2C01 | 1 | OLED-TH_L38.0-W12.0_HS91L02W2C01
30 | U2 | SOT-23-5 | 1 | TLV73333PDBV
31 | U3 | SOIC-8_5.23x5.23mm_P1.27mm | 1 | W25Q128JVS
32 | R6,R4,R8 | R_0402_1005Metric | 3 | 1k
33 | U1 | RP2350-QFN-60-1EP_7x7_P0.4mm_EP3.4x3.4mm_ThermalVias | 1 | RP2350_60QFN
34 | L1 | L_pol_2016 | 1 | 3.3u
35 | REF** | R_0402 | 1 | R_0402_1005Metric
36 | R1 | R_0402_1005Metric | 1 | 33
37 | Y1 | Crystal_SMD_3225-4Pin_3.2x2.5mm | 1 | ABM8-272-T3
38 | C19 | CP_EIA-3528-21_Kemet-B | 1 | 100u
39 | USB2 | USB_A_TE_292303-7_Horizontal | 1 | USB_A

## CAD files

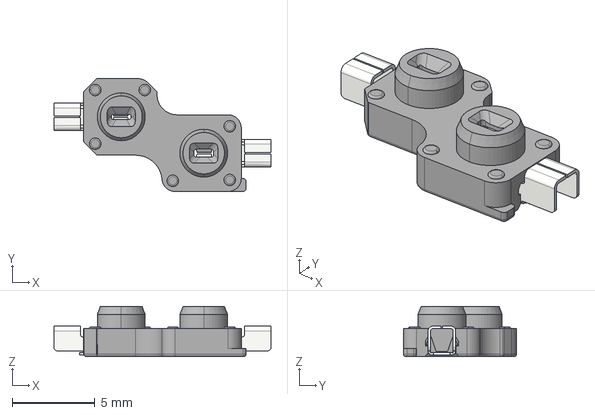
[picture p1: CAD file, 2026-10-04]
3dmodels/SW_Hotswap_Kailh_Choc_V1.step
13.2 x 6.85 x 3.05 mm

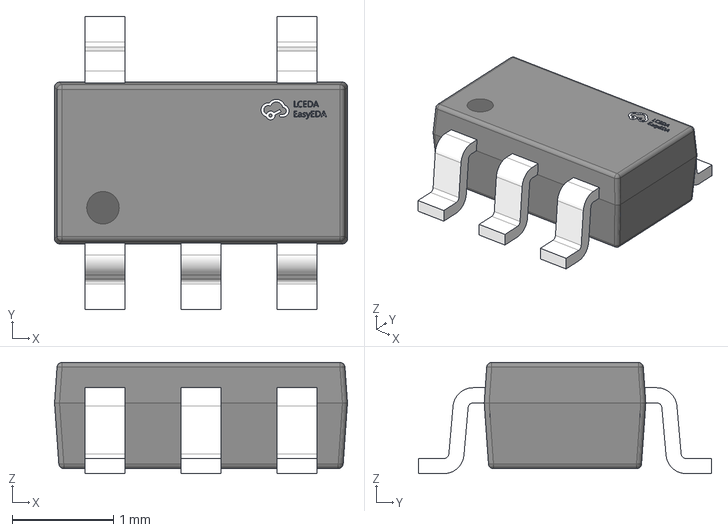
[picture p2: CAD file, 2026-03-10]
EASYEDA_MODELS/SOT-23-5_L2.9-W1.6-P0.95-LS2.8-BR.step
2.90 x 2.90 x 1.10 mm

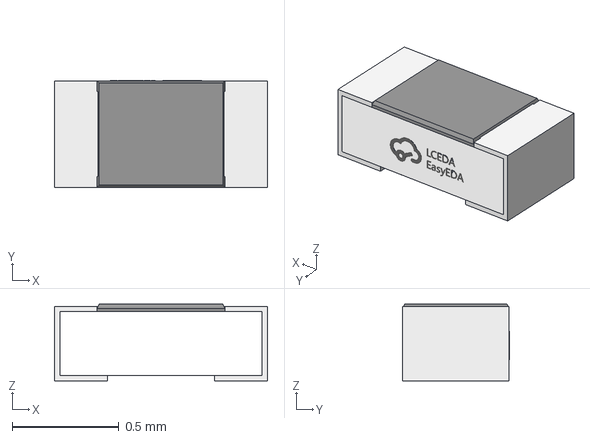
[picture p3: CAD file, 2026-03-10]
EASYEDA_MODELS/R0402_L1.0-W0.5-H0.4.step
1.00 x 0.501 x 0.36 mm

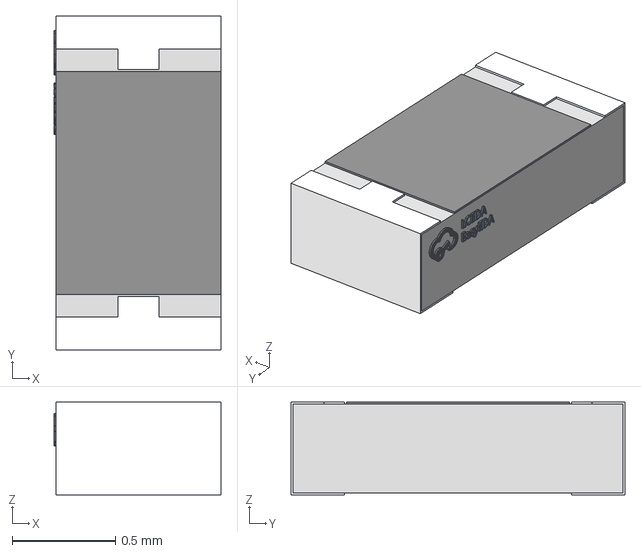
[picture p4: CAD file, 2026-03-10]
EASYEDA_MODELS/R0603.step
0.81 x 1.62 x 0.45 mm

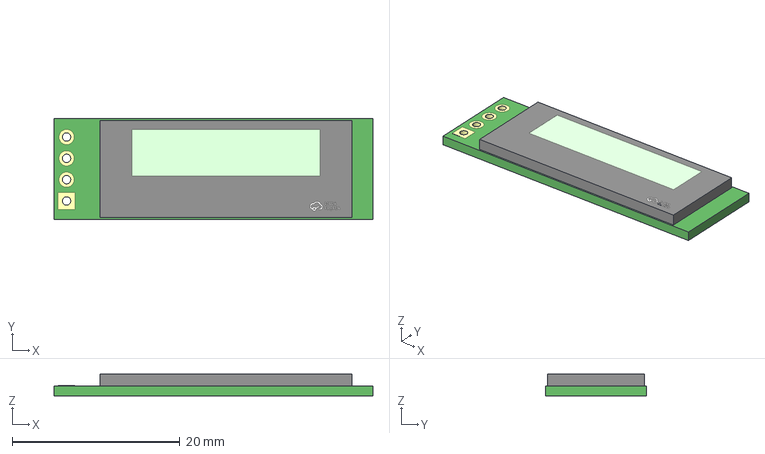
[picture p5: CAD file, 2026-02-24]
EASYEDA_MODELS/OLED-TH_L38.0-W12.0_HS91L02W2C01.step
38.0 x 12.0 x 2.62 mm

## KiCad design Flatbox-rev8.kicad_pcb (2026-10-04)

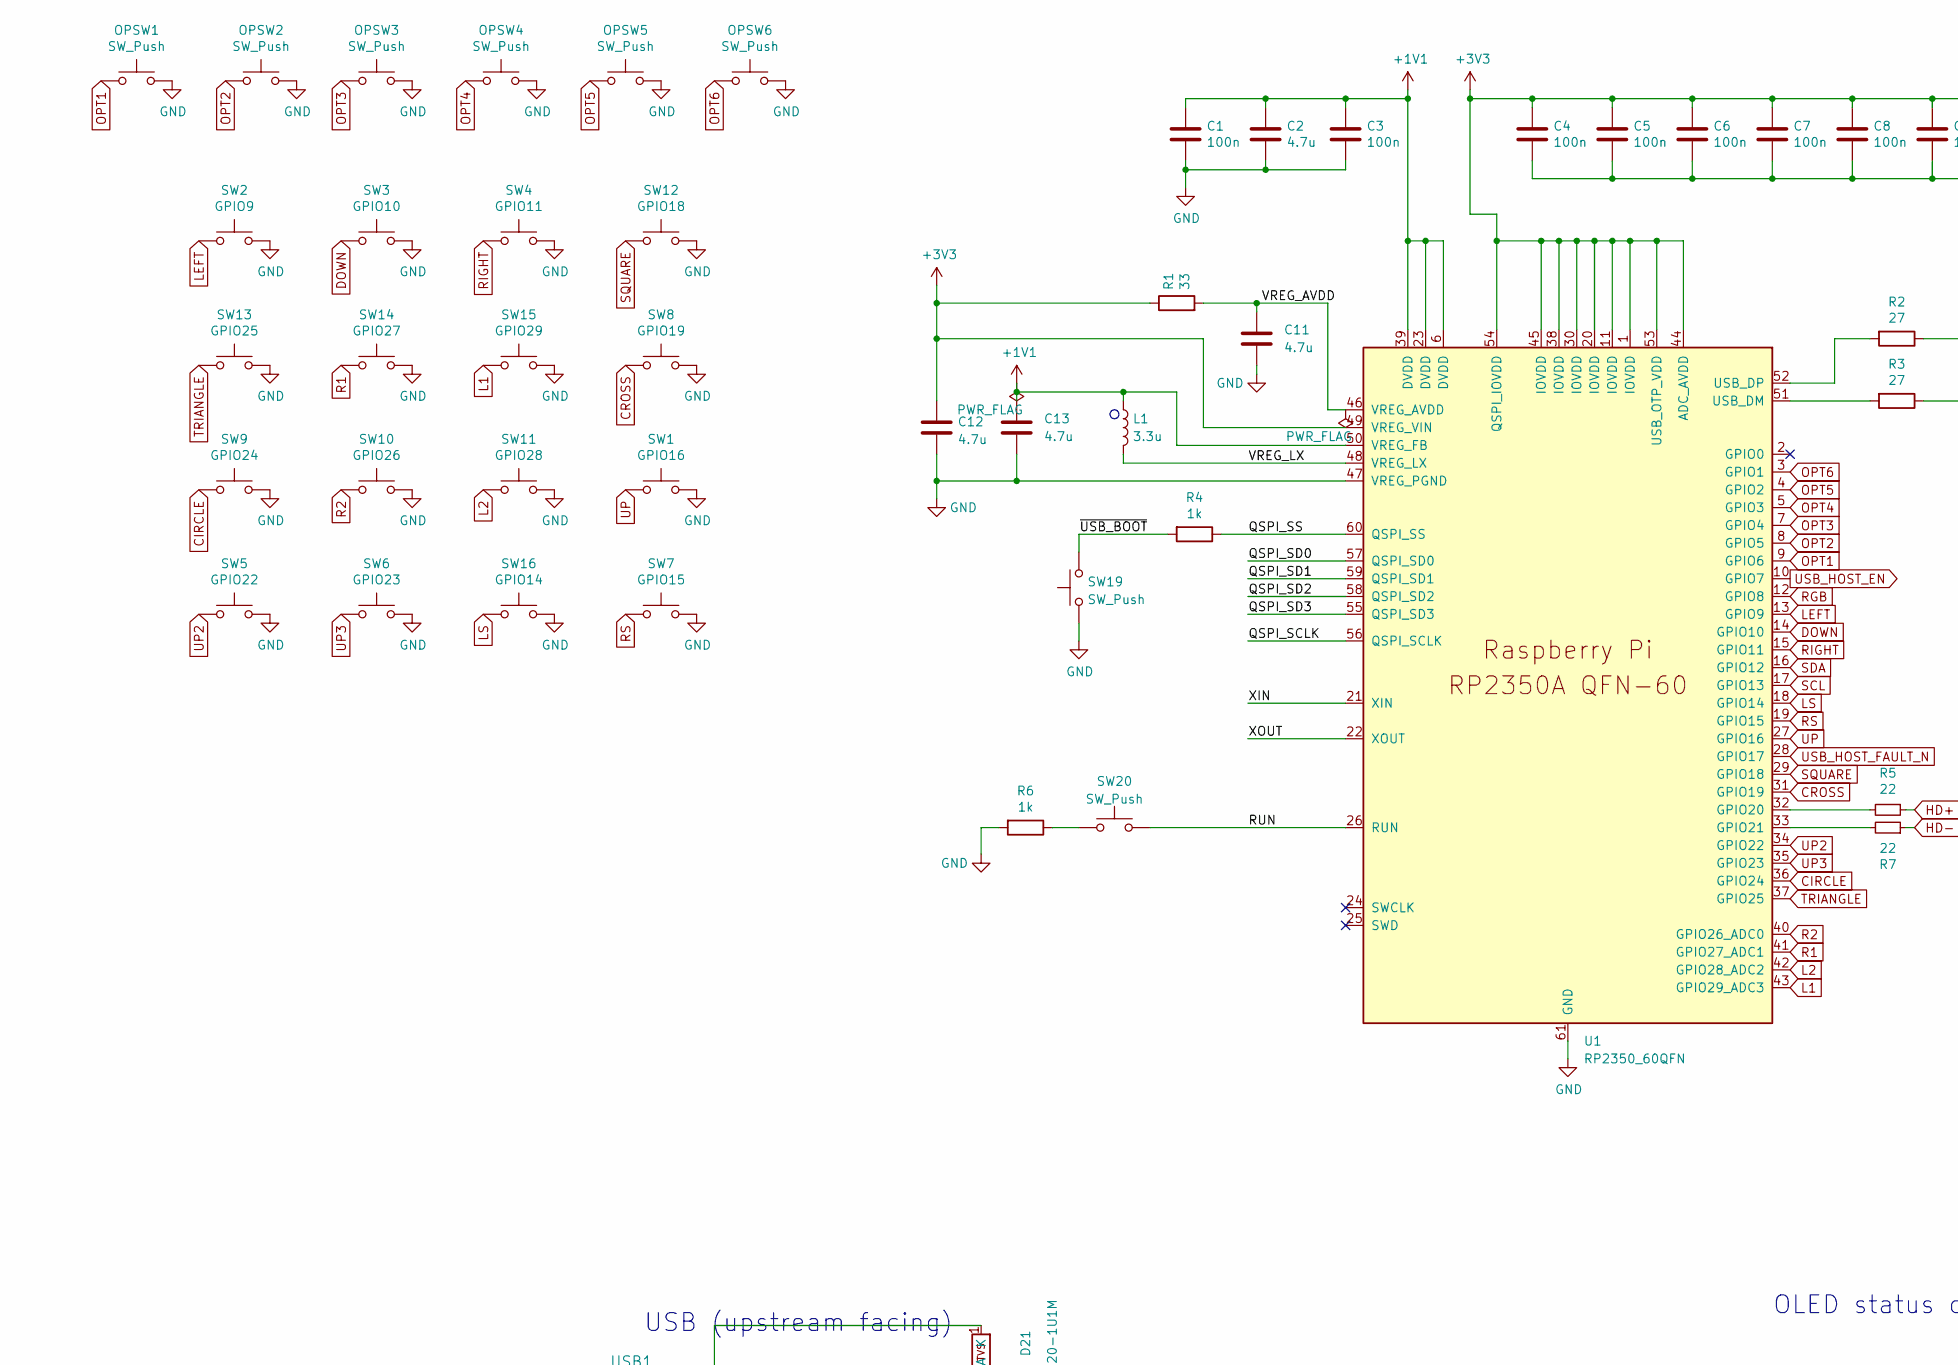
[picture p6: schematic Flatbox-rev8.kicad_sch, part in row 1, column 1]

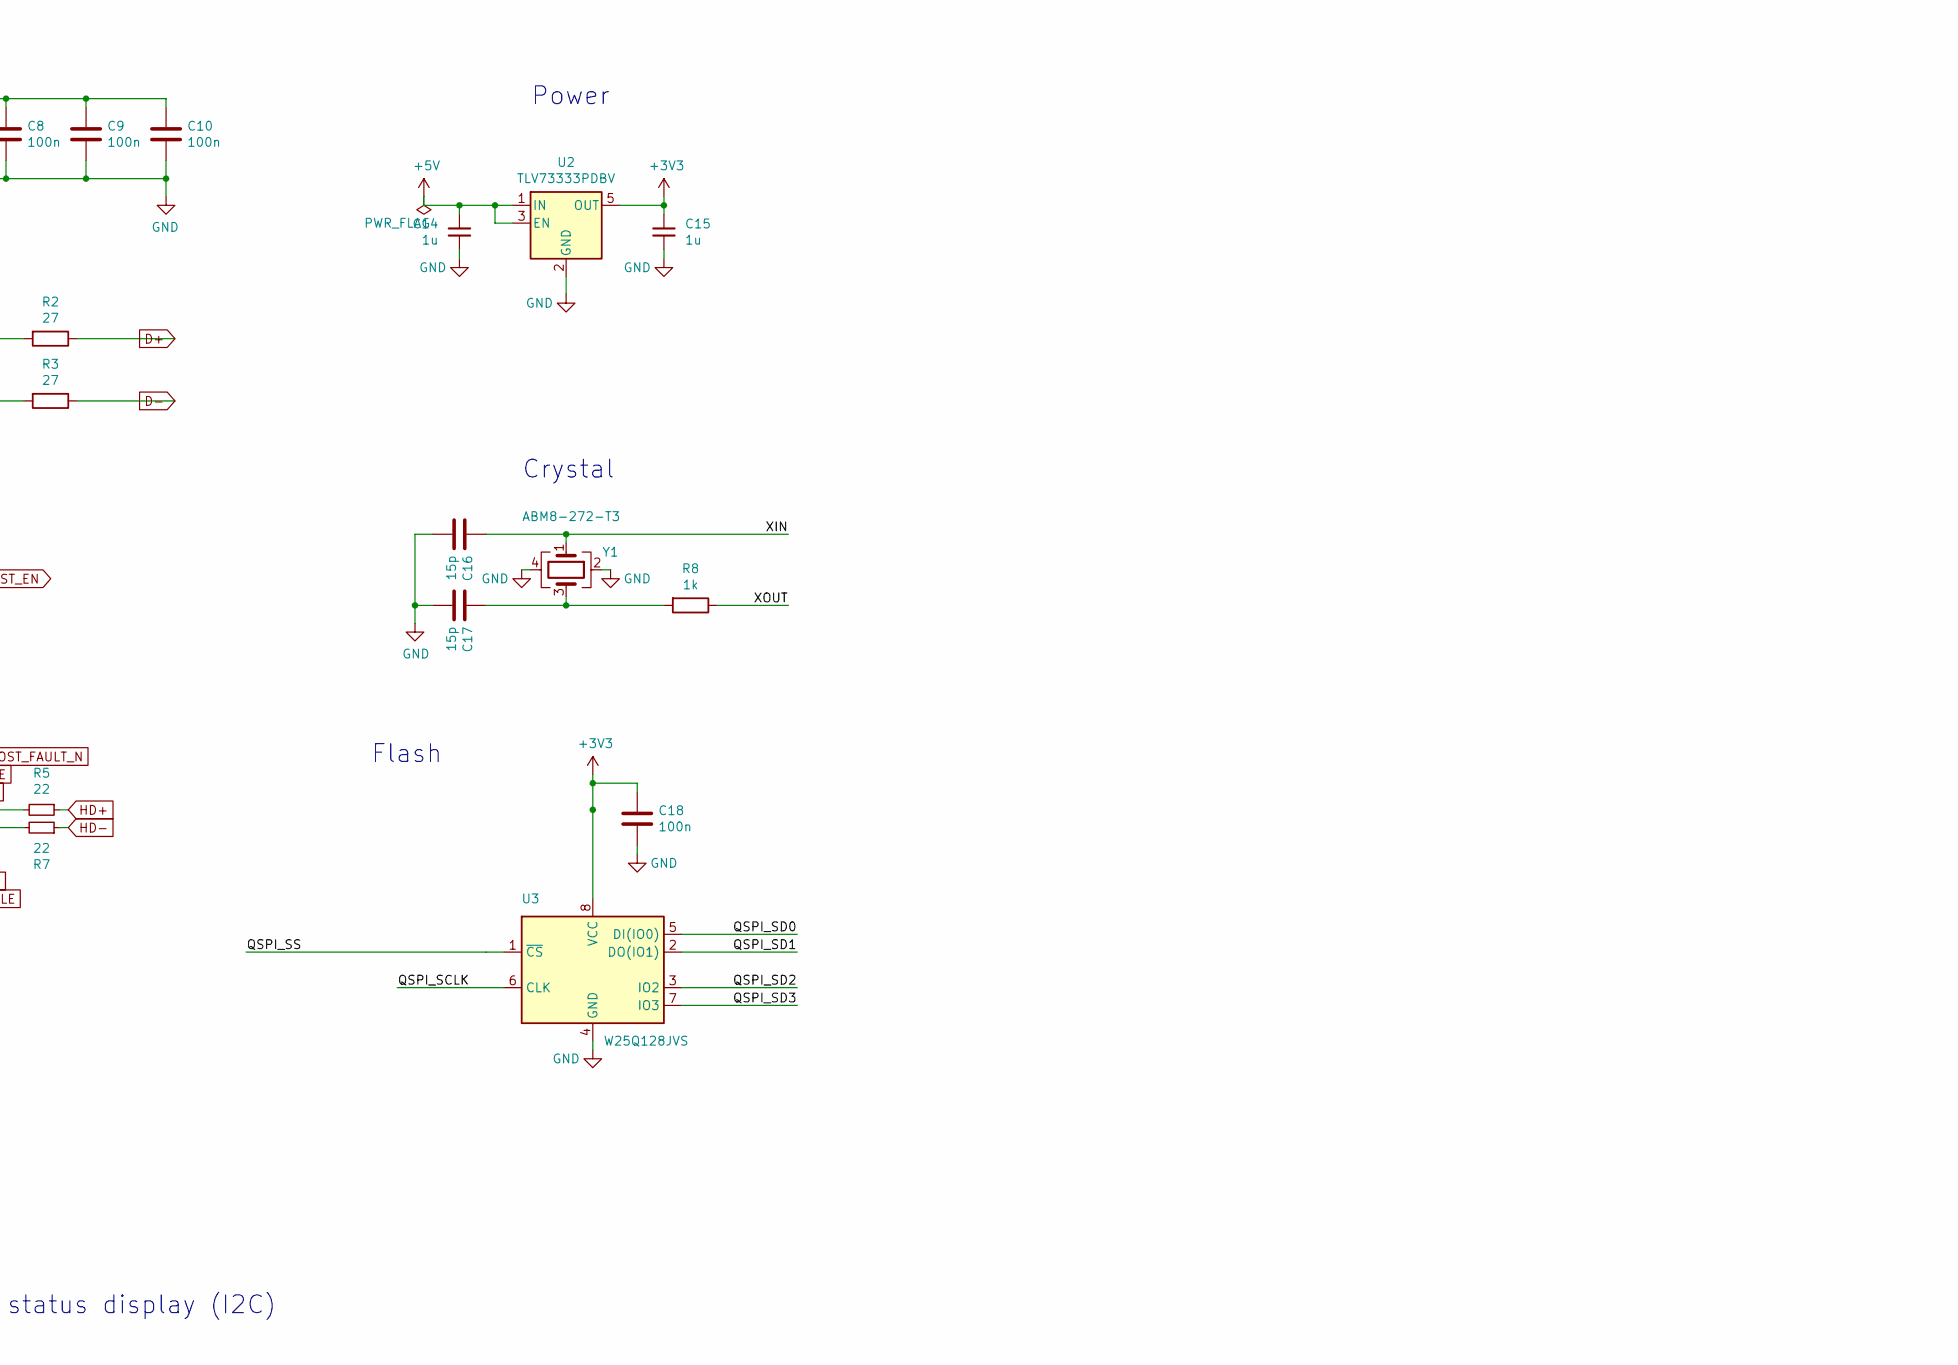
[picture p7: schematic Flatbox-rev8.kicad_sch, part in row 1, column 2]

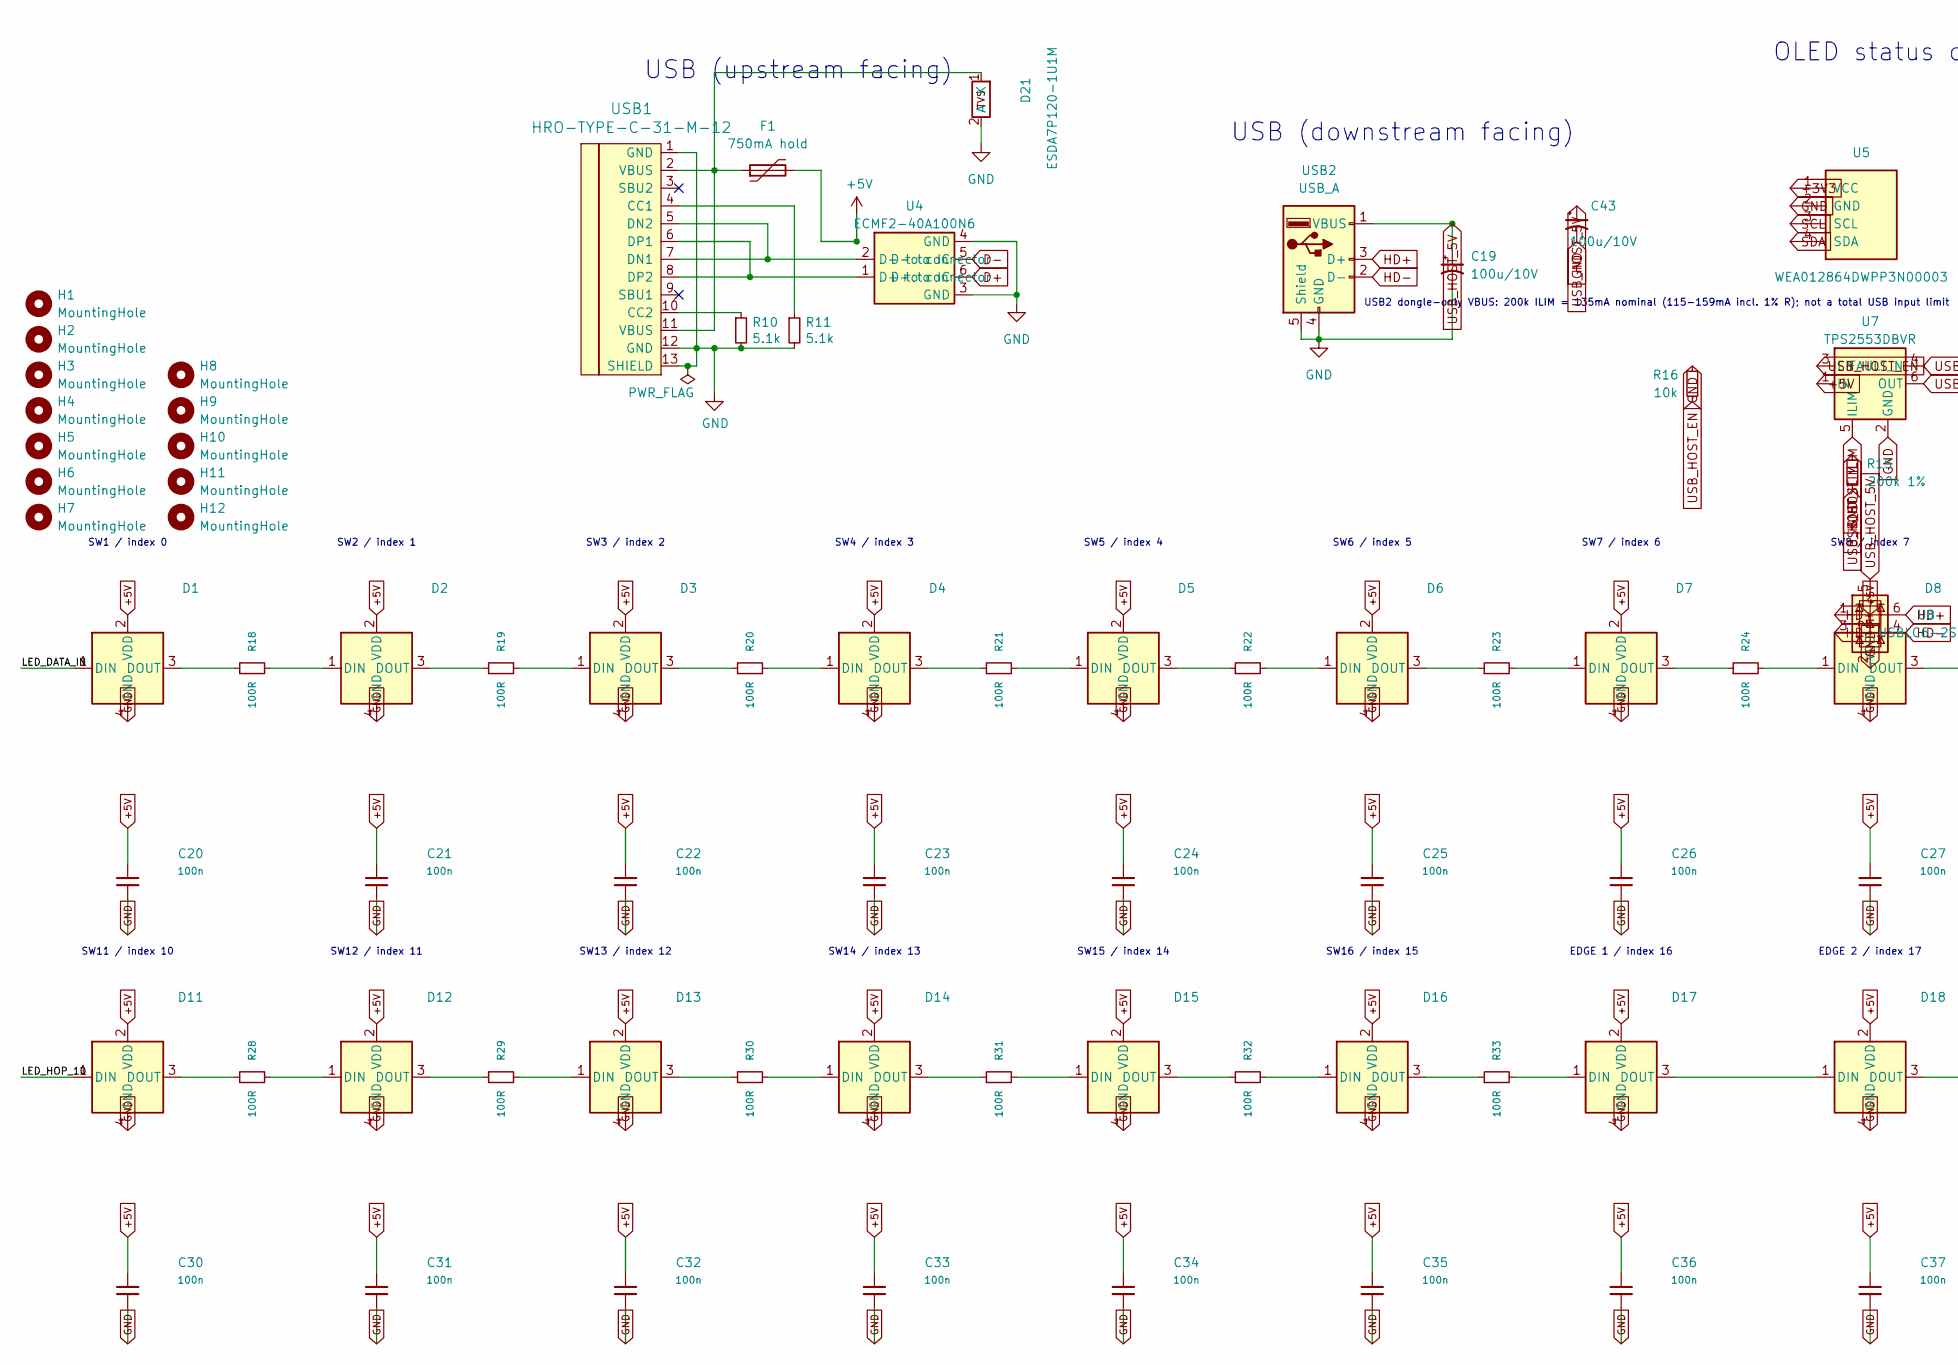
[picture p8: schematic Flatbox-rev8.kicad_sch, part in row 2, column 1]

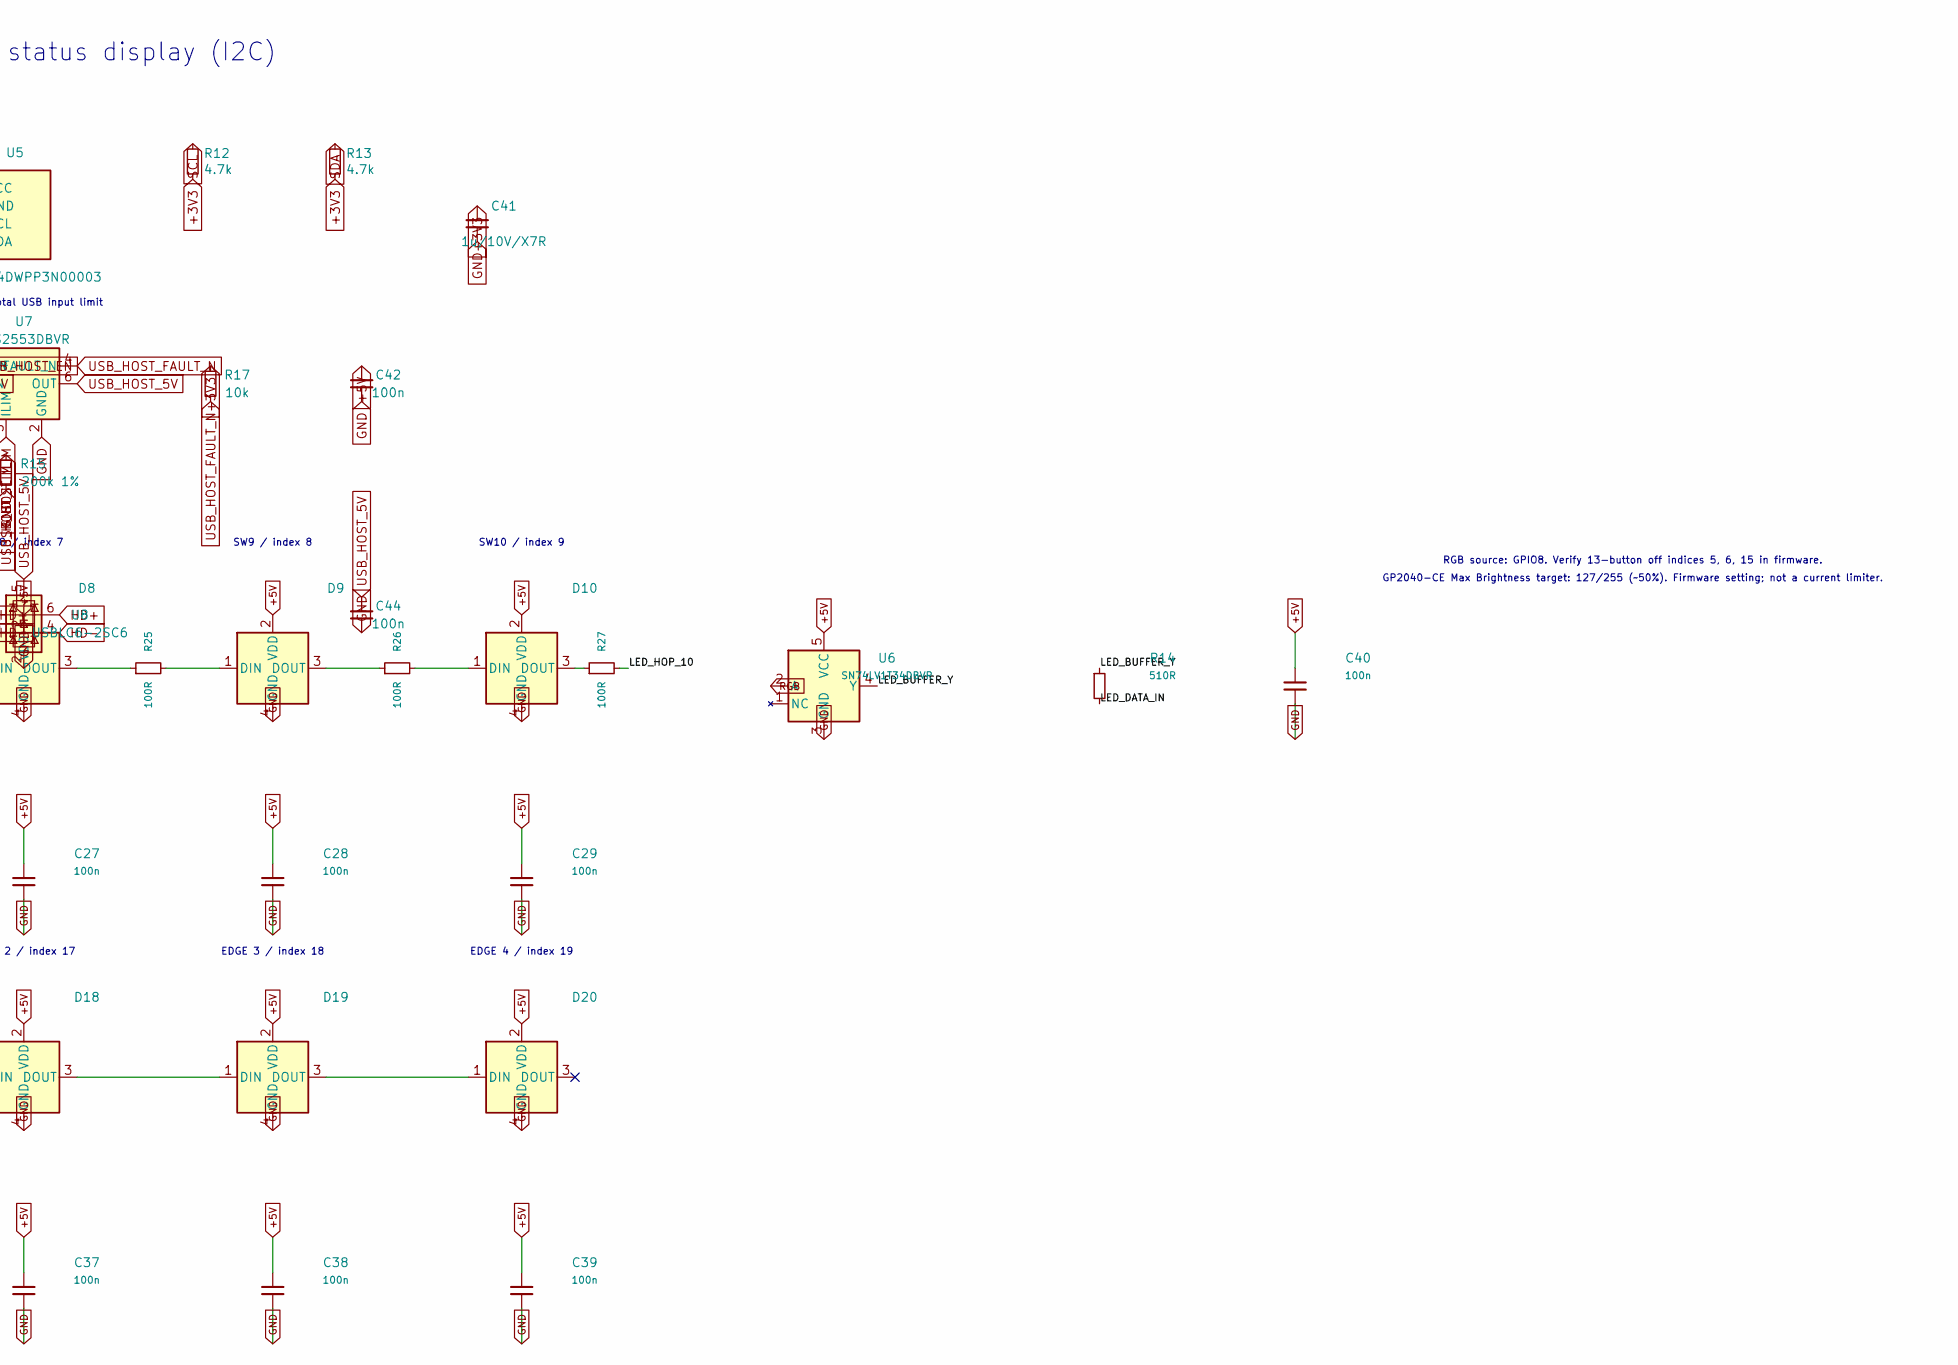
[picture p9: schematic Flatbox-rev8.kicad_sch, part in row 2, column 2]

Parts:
C1, C3, C4, C5, C6, C7, C8, C9, C10, C18: 100n; C_0402_1005Metric; LCSC C1525
C2, C11: 4.7u; C_0402_1005Metric; LCSC C23733
C12, C13: 4.7u; C_0402_1005Metric_small_pads; LCSC C23733
C14, C15: 1u; C_0402_1005Metric; LCSC C52923
C16, C17: 15p; C_0402_1005Metric; LCSC C1548
C19, C43: 100u/10V; CP_KEMET_T520B_3528_21; MPN T520B107M010ATE070; LCSC C600583
C20, C21, C22, C23, C24, C25, C26, C27, C28, C29, C30, C31, C32, C33, C34, C35, C36, C37, C38, C39, C40: 100n; C_0402_1005Metric_small_pads; MPN CL05B104KO5NNNC; LCSC C1525
C41: 1u/10V/X7R; C_0603_1608Metric
C42, C44: 100n; C_0402_1005Metric; MPN CL05B104KO5NNNC; LCSC C1525
D1, D2, D3, D4, D5, D6, D7, D8, D9, D10, D11, D12, D13, D14, D15, D16, D17, D18, D19, D20: SK6805-EC15; LED_SK6805_EC15_Optical; MPN SK6805-EC15; LCSC C2890035
D21: ESDA7P120-1U1M; ST_QFN-2L_1.6x1.0mm; MPN ESDA7P120-1U1M; LCSC C2969802
F1: 750mA hold; Fuse_0805_2012Metric; MPN SMD0805-075-12V; LCSC C19108399
H1, H2, H3, H4, H5, H6, H7: MountingHole; MountingHole_6.4mm_M6
H8, H9, H10, H11, H12: MountingHole; MountingHole_2.2mm_M2
L1: 3.3u; L_pol_2016; LCSC C42411119
OPSW1, OPSW2, OPSW3, OPSW4, OPSW5, OPSW6: SW_Push; SW_PUSH_6mm_H5mm
R1: 33; R_0402_1005Metric; LCSC C25105
R2, R3: 27; R_0402_1005Metric; LCSC C138021
R4, R6, R8: 1k; R_0402_1005Metric; LCSC C11702
R5, R7: 22; R_0402_1005Metric; LCSC C102906
R10, R11: 5.1k; R_0402_1005Metric; LCSC C25905
R12, R13: 4.7k; R_0603_Compact; MPN 0603WAF4701T5E; LCSC C23162
R14: 510R; R_0402_1005Metric; MPN 0402WGF5100TCE; LCSC C25123
R15: 200k 1%; R_0402_1005Metric; MPN 0402WGF2003TCE; LCSC C25764
R16, R17: 10k; R_0402_1005Metric; MPN 0402WGF1002TCE; LCSC C25744
R18, R19, R20, R21, R22, R23, R24, R25, R26, R27, R28, R29, R30, R31, R32, R33: 100R; R_0402_1005Metric; MPN 0402WGF1000TCE; LCSC C25076
SW1: GPIO16; SW_Hotswap_Kailh_Choc_V1V2_3D_Optical
SW2: GPIO9; SW_Hotswap_Kailh_Choc_V1V2_3D_Optical
SW3: GPIO10; SW_Hotswap_Kailh_Choc_V1V2_3D_Optical
SW4: GPIO11; SW_Hotswap_Kailh_Choc_V1V2_3D_Optical
SW5: GPIO22; SW_Hotswap_Kailh_Choc_V1V2_3D_Optical
SW6: GPIO23; SW_Hotswap_Kailh_Choc_V1V2_3D_Optical
SW7: GPIO15; SW_Hotswap_Kailh_Choc_V1V2_3D_Optical
SW8: GPIO19; SW_Hotswap_Kailh_Choc_V1V2_3D_Optical
SW9: GPIO24; SW_Hotswap_Kailh_Choc_V1V2_3D_Optical
SW10: GPIO26; SW_Hotswap_Kailh_Choc_V1V2_3D_Optical
SW11: GPIO28; SW_Hotswap_Kailh_Choc_V1V2_3D_Optical
SW12: GPIO18; SW_Hotswap_Kailh_Choc_V1V2_3D_Optical
SW13: GPIO25; SW_Hotswap_Kailh_Choc_V1V2_3D_Optical
SW14: GPIO27; SW_Hotswap_Kailh_Choc_V1V2_3D_Optical
SW15: GPIO29; SW_Hotswap_Kailh_Choc_V1V2_3D_Optical
SW16: GPIO14; SW_Hotswap_Kailh_Choc_V1V2_3D_Optical
SW19, SW20: SW_Push; SW_C318884_FabOnly; LCSC C318884
U1: RP2350_60QFN; RP2350-QFN-60-1EP_7x7_P0.4mm_EP3.4x3.4mm_ThermalVias; LCSC C42411118
U2: TLV73333PDBV; SOT-23-5; LCSC C134139
U3: W25Q128JVS; SOIC-8_5.23x5.23mm_P1.27mm; LCSC C97521
U4: ECMF2-40A100N6; MPN ECMF2-40A100N6; LCSC C5267592
U5: WEA012864DWPP3N00003; OLED_WEA012864DWPP3N00003; MPN WEA012864DWPP3N00003
U6: SN74LV1T34DBVR; SOT-23-5; MPN SN74LV1T34DBVR; LCSC C100024
U7: TPS2553DBVR; SOT-23-6; MPN TPS2553DBVR; LCSC C55266
U8: USBLC6-2SC6; SOT-23-6; MPN USBLC6-2SC6; LCSC C7519
USB1: HRO-TYPE-C-31-M-12; HRO-TYPE-C-31-M-12-Assembly; LCSC C165948
USB2: USB_A; C2763302; LCSC C2763302
Y1: ABM8-272-T3; Crystal_SMD_3225-4Pin_3.2x2.5mm; LCSC C20625731

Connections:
+1V1: C1.1, C2.1, C3.1, C13.1, L1.1, U1.6 (DVDD), U1.23 (DVDD), U1.39 (DVDD), U1.50 (VREG_FB)
+3V3: C4.1, C5.1, C6.1, C7.1, C8.1, C9.1, C10.1, C12.1, C15.1, C18.1, C41.1, R1.1, R12.2, R13.2, R17.1, U1.1 (IOVDD), U1.11 (IOVDD), U1.20 (IOVDD), U1.30 (IOVDD), U1.38 (IOVDD), U1.44 (ADC_AVDD), U1.45 (IOVDD), U1.49 (VREG_VIN), U1.53 (USB_OTP_VDD), U1.54 (QSPI_IOVDD), U2.5 (OUT), U3.8 (VCC), U5.1 (VCC)
+5V: C14.1, C20.1, C21.1, C22.1, C23.1, C24.1, C25.1, C26.1, C27.1, C28.1, C29.1, C30.1, C31.1, C32.1, C33.1, C34.1, C35.1, C36.1, C37.1, C38.1, C39.1, C40.1, C42.1, D1.2 (VDD), D2.2 (VDD), D3.2 (VDD), D4.2 (VDD), D5.2 (VDD), D6.2 (VDD), D7.2 (VDD), D8.2 (VDD), D9.2 (VDD), D10.2 (VDD), D11.2 (VDD), D12.2 (VDD), D13.2 (VDD), D14.2 (VDD), D15.2 (VDD), D16.2 (VDD), D17.2 (VDD), D18.2 (VDD), D19.2 (VDD), D20.2 (VDD), F1.2, U2.1 (IN), U2.3 (EN), U6.5 (VCC), U7.1 (IN)
/LED_BUFFER_Y: R14.1, U6.4 (Y)
/LED_DATA_IN: D1.1 (DIN), R14.2
/LED_HOP_10: D11.1 (DIN), R27.2
/QSPI_SCLK: U1.56 (QSPI_SCLK), U3.6 (CLK)
/QSPI_SD0: U1.57 (QSPI_SD0), U3.5 (DI(IO0))
/QSPI_SD1: U1.59 (QSPI_SD1), U3.2 (DO(IO1))
/QSPI_SD2: U1.58 (QSPI_SD2), U3.3 (IO2)
/QSPI_SD3: U1.55 (QSPI_SD3), U3.7 (IO3)
/QSPI_SS: R4.1, U1.60 (QSPI_SS), U3.1 (~CS)
/RUN: SW20.2, U1.26 (RUN)
/VREG_AVDD: C11.1, R1.2, U1.46 (VREG_AVDD)
/VREG_LX: L1.2, U1.48 (VREG_LX)
/XIN: C16.1, U1.21 (XIN), Y1.1
/XOUT: R8.1, U1.22 (XOUT)
/~USB_BOOT: R4.2, SW19.2
CIRCLE: SW9.1, U1.36 (GPIO24)
CROSS: SW8.1, U1.31 (GPIO19)
D+: R2.1, U4.6 (D+_to_IC)
D-: R3.1, U4.5 (D-_to_IC)
DOWN: SW3.1, U1.14 (GPIO10)
GND: C1.2, C2.2, C3.2, C4.2, C5.2, C6.2, C7.2, C8.2, C9.2, C10.2, C11.2, C12.2, C13.2, C14.2, C15.2, C16.2, C17.2, C18.2, C19.2, C20.2, C21.2, C22.2, C23.2, C24.2, C25.2, C26.2, C27.2, C28.2, C29.2, C30.2, C31.2, C32.2, C33.2, C34.2, C35.2, C36.2, C37.2, C38.2, C39.2, C40.2, C41.2, C42.2, C43.2, C44.2, D1.4 (GND), D2.4 (GND), D3.4 (GND), D4.4 (GND), D5.4 (GND), D6.4 (GND), D7.4 (GND), D8.4 (GND), D9.4 (GND), D10.4 (GND), D11.4 (GND), D12.4 (GND), D13.4 (GND), D14.4 (GND), D15.4 (GND), D16.4 (GND), D17.4 (GND), D18.4 (GND), D19.4 (GND), D20.4 (GND), D21.2 (A), OPSW1.2, OPSW2.2, OPSW3.2, OPSW4.2, OPSW5.2, OPSW6.2, R6.2, R10.2, R11.2, R15.2, R16.1, SW1.2, SW2.2, SW3.2, SW4.2, SW5.2, SW6.2, SW7.2, SW8.2, SW9.2, SW10.2, SW11.2, SW12.2, SW13.2, SW14.2, SW15.2, SW16.2, SW19.1, U1.47 (VREG_PGND), U1.61 (GND), U2.2 (GND), U3.4 (GND), U4.3 (GND), U4.4 (GND), U5.2 (GND), U6.3 (GND), U7.2 (GND), U8.2 (GND), USB1.1 (GND), USB1.12 (GND), USB1.13 (SHIELD), USB2.4 (GND), USB2.5 (Shield), Y1.2, Y1.4
HD+: R5.1, U8.1 (I/O1), U8.6 (I/O1), USB2.3 (D+)
HD-: R7.1, U8.3 (I/O2), U8.4 (I/O2), USB2.2 (D-)
L1: SW15.1, U1.43 (GPIO29_ADC3)
L2: SW11.1, U1.42 (GPIO28_ADC2)
LEFT: SW2.1, U1.13 (GPIO9)
LS: SW16.1, U1.18 (GPIO14)
unnamed: C17.1, R8.2, Y1.3
unnamed: D1.3 (DOUT), R18.1
unnamed: D2.1 (DIN), R18.2
unnamed: D2.3 (DOUT), R19.1
unnamed: D3.1 (DIN), R19.2
unnamed: D3.3 (DOUT), R20.1
unnamed: D4.1 (DIN), R20.2
unnamed: D4.3 (DOUT), R21.1
unnamed: D5.1 (DIN), R21.2
unnamed: D5.3 (DOUT), R22.1
unnamed: D6.1 (DIN), R22.2
unnamed: D6.3 (DOUT), R23.1
unnamed: D7.1 (DIN), R23.2
unnamed: D7.3 (DOUT), R24.1
unnamed: D8.1 (DIN), R24.2
unnamed: D8.3 (DOUT), R25.1
unnamed: D9.1 (DIN), R25.2
unnamed: D9.3 (DOUT), R26.1
unnamed: D10.1 (DIN), R26.2
unnamed: D10.3 (DOUT), R27.1
unnamed: D11.3 (DOUT), R28.1
unnamed: D12.1 (DIN), R28.2
unnamed: D12.3 (DOUT), R29.1
unnamed: D13.1 (DIN), R29.2
unnamed: D13.3 (DOUT), R30.1
unnamed: D14.1 (DIN), R30.2
unnamed: D14.3 (DOUT), R31.1
unnamed: D15.1 (DIN), R31.2
unnamed: D15.3 (DOUT), R32.1
unnamed: D16.1 (DIN), R32.2
unnamed: D16.3 (DOUT), R33.1
unnamed: D17.1 (DIN), R33.2
unnamed: D17.3 (DOUT), D18.1 (DIN)
unnamed: D18.3 (DOUT), D19.1 (DIN)
unnamed: D19.3 (DOUT), D20.1 (DIN)
unnamed: D21.1 (K), F1.1, USB1.2 (VBUS), USB1.11 (VBUS)
unnamed: R6.1, SW20.1
unnamed: R5.2, U1.32 (GPIO20)
unnamed: R7.2, U1.33 (GPIO21)
unnamed: R3.2, U1.51 (USB_DM)
unnamed: R2.2, U1.52 (USB_DP)
unnamed: U4.1 (D+_to_connector), USB1.6 (DP1), USB1.8 (DP2)
unnamed: U4.2 (D-_to_connector), USB1.5 (DN2), USB1.7 (DN1)
unnamed: R11.1, USB1.4 (CC1)
unnamed: R10.1, USB1.10 (CC2)
OPT1: OPSW1.1, U1.9 (GPIO6)
OPT2: OPSW2.1, U1.8 (GPIO5)
OPT3: OPSW3.1, U1.7 (GPIO4)
OPT4: OPSW4.1, U1.5 (GPIO3)
OPT5: OPSW5.1, U1.4 (GPIO2)
OPT6: OPSW6.1, U1.3 (GPIO1)
R1: SW14.1, U1.41 (GPIO27_ADC1)
R2: SW10.1, U1.40 (GPIO26_ADC0)
RGB: U1.12 (GPIO8), U6.2 (A)
RIGHT: SW4.1, U1.15 (GPIO11)
RS: SW7.1, U1.19 (GPIO15)
SCL: R12.1, U1.17 (GPIO13), U5.3 (SCL)
SDA: R13.1, U1.16 (GPIO12), U5.4 (SDA)
SQUARE: SW12.1, U1.29 (GPIO18)
TRIANGLE: SW13.1, U1.37 (GPIO25)
UP: SW1.1, U1.27 (GPIO16)
UP2: SW5.1, U1.34 (GPIO22)
UP3: SW6.1, U1.35 (GPIO23)
USB_HOST_5V: C19.1, C43.1, C44.1, U7.6 (OUT), U8.5 (VBUS), USB2.1 (VBUS)
USB_HOST_EN: R16.2, U1.10 (GPIO7), U7.3 (EN)
USB_HOST_FAULT_N: R17.2, U1.28 (GPIO17), U7.4 (FAULT_N)
USB_HOST_ILIM: R15.1, U7.5 (ILIM)

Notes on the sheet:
USB (downstream facing)
Flash
Crystal
USB (upstream facing)
OLED status display (I2C)
Power
USB2 dongle-only VBUS: 200k ILIM = 135mA nominal (115-159mA incl. 1% R); not a total USB input limit
SW1 / index 0
SW2 / index 1
SW3 / index 2
SW4 / index 3
SW5 / index 4
SW6 / index 5
SW7 / index 6
SW8 / index 7
SW9 / index 8
SW10 / index 9
SW11 / index 10
SW12 / index 11
SW13 / index 12
SW14 / index 13
SW15 / index 14
SW16 / index 15
EDGE 1 / index 16
EDGE 2 / index 17
EDGE 3 / index 18
EDGE 4 / index 19
RGB source: GPIO8. Verify 13-button off indices 5, 6, 15 in firmware.
GP2040-CE Max Brightness target: 127/255 (~50%). Firmware setting; not a current limiter.

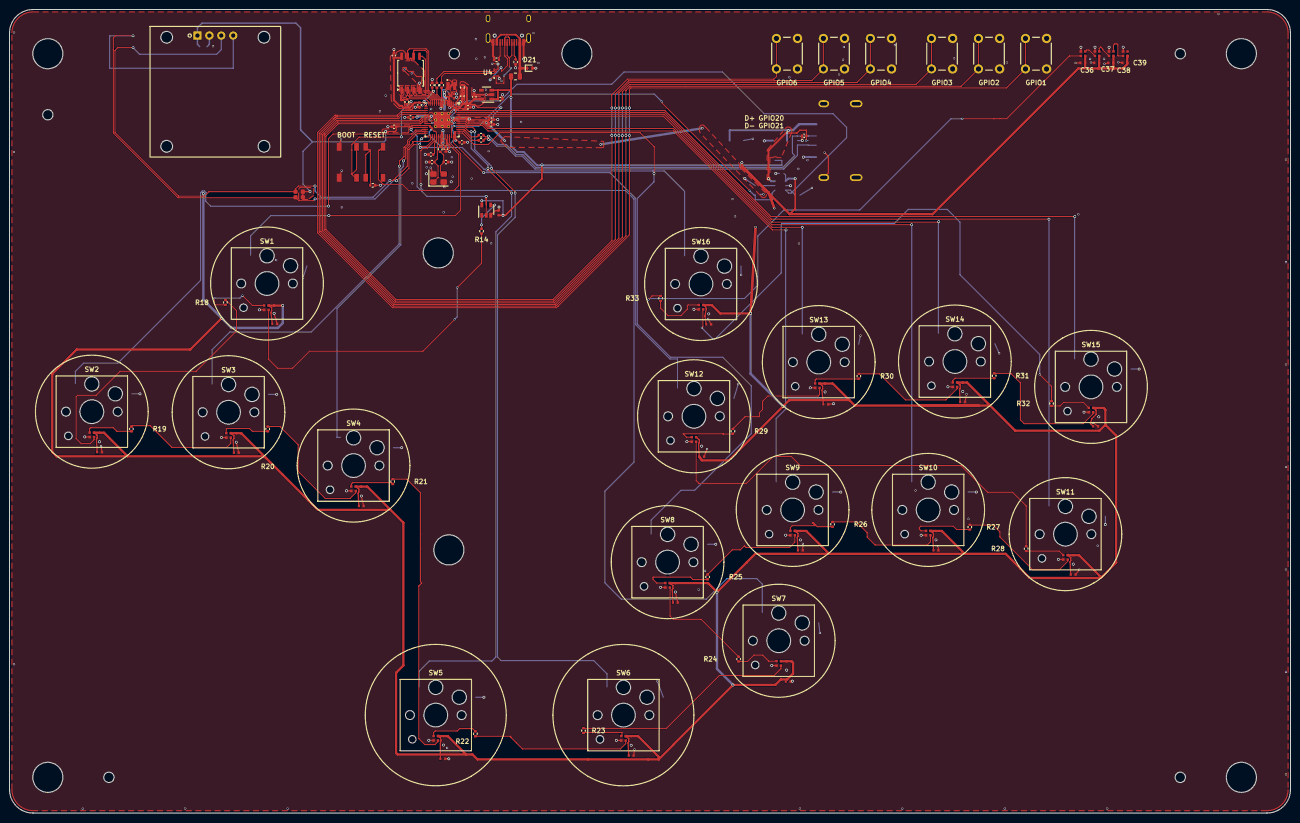
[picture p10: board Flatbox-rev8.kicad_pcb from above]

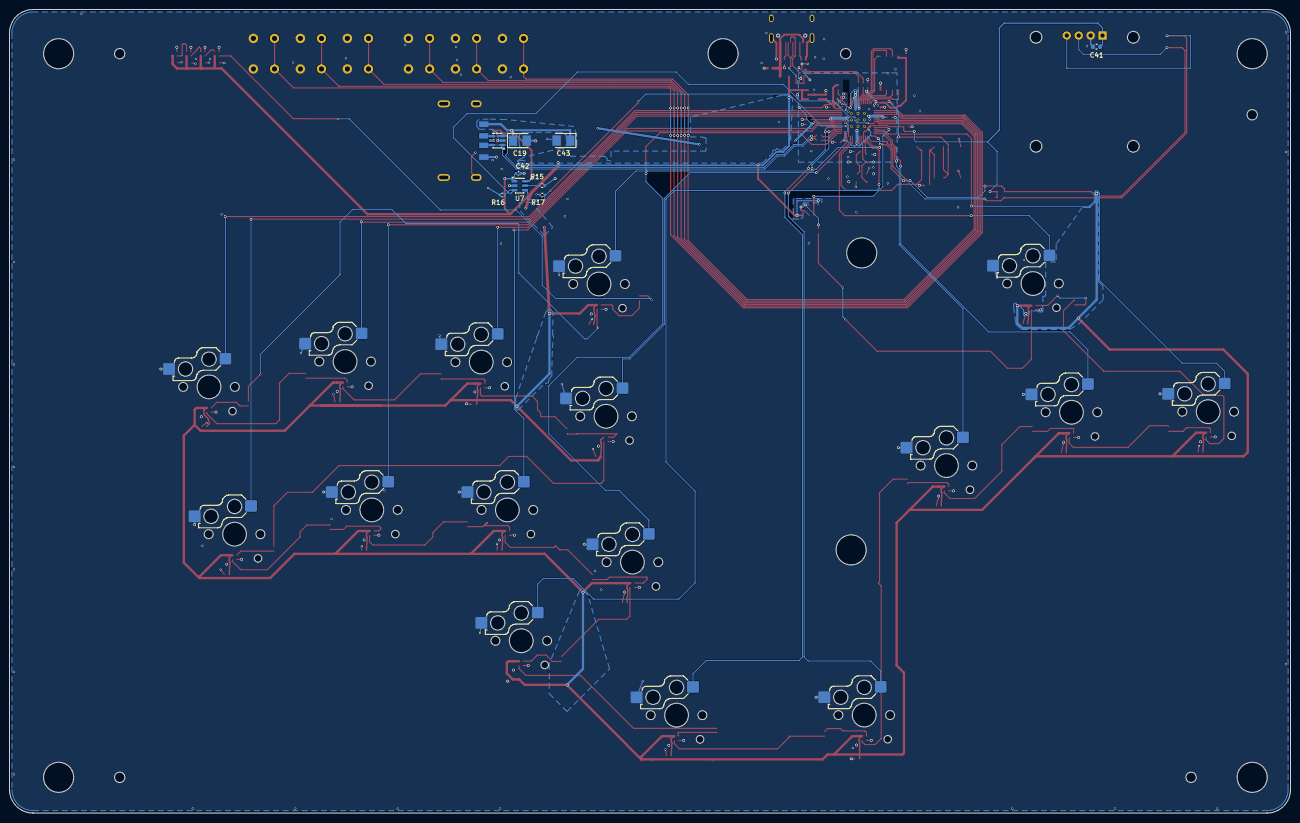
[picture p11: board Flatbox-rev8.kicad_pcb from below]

Board: 4 copper layers, 272.6 x 171.0 mm, 146 parts (10 on the bottom side), 97 nets.

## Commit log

2026-02-10 Added pinout for case rgb and switch RGB, moved USB to suitable location
    [Flatbox-rev8.kicad_pcb, Flatbox-rev8.kicad_sch]
2026-02-11 Redone butotn layout (sort of) and localized general area for booter location
    - MAKE NEW FOOTPRINT FOR LED + SWITCH COMBO
    [Flatbox-rev8.kicad_pcb]
2026-02-23 Done up switch traces for main directional and command input
    Done up switch traces for main directional and command input
    Need to redo schematic for LS RS, Up directional chaining and RGB SMD
    [Flatbox-rev8.kicad_pcb, Flatbox-rev8.kicad_sch]
2026-02-24 redone socket, adding RGB lighting and pathing
    [Flatbox-rev8.kicad_pcb, OLED-TH_L38.0-W12.0_HS91L02W2C01.step]
2026-03-10 final design inshallah
    [Flatbox-rev8-B_Cu.gbl, Flatbox-rev8-B_Fab.gbr, Flatbox-rev8-B_Mask.gbs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]
2026-09-24 Document PHBox design state and sync KiCad sources
    [Flatbox-rev8.kicad_pcb, Flatbox-rev8.kicad_sch]
2026-09-24 Stop tracking KiCad lock files
2026-10-04 Save validated PHBox design and document testing and manufacturing workflow
    [Flatbox-rev8.kicad_pcb, Flatbox-rev8.kicad_sch, SW_Hotswap_Kailh_Choc_V1.step]
